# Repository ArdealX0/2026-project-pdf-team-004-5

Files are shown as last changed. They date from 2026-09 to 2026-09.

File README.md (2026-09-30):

Repository Information:

**[Final Report Related Info]**

Lab 004 Team 5-Design Documentation.pdf is the design documentation file. 
  - This file was maintained on Google Doc and the final version is exported here.
  
Lab 004 Team 5-Design Final Report.pdf is the final report.

**[Final Design CAD]**

Model_Parts/Showcase Vehicle v2 CAD.zip contains all the step files of the final project design vehicle exported form OnShape

**[Final Design Code]**

esp32_left_n20_motor_controls.ino is the showcase code for 1 of the ESP32s.
  - Responsible for vehicle drive and pick-up wheel drive.
  
esp32_right_colour_sensing_code.ino is the showcase code for the other ESP32.
  - Responsible for servo actuation and colour sensing.

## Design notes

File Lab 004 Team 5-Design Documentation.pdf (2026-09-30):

# MSE 2202B DESIGN DOCUMENT LAB 4 TEAM 5

## SPECIFICATION AND PLANNING PHASE

Tasks Completed February 13, 2026

- Problem Statement Established
- Goals & Constraints Established
- Vehicle Subsystem Trade Studies Completed

Problem Statement:

Resource extraction operations in hazardous environments need a way to autonomously navigate unknown terrain to identify and retrieve high-value objects (erasers), especially where long distance communication is unreliable. Thus, the objective of this project is to design and build an autonomous mobile robot capable of collecting pencil erasers from a defined area, separating them by colour, and returning them to a base location within a fixed time limit.

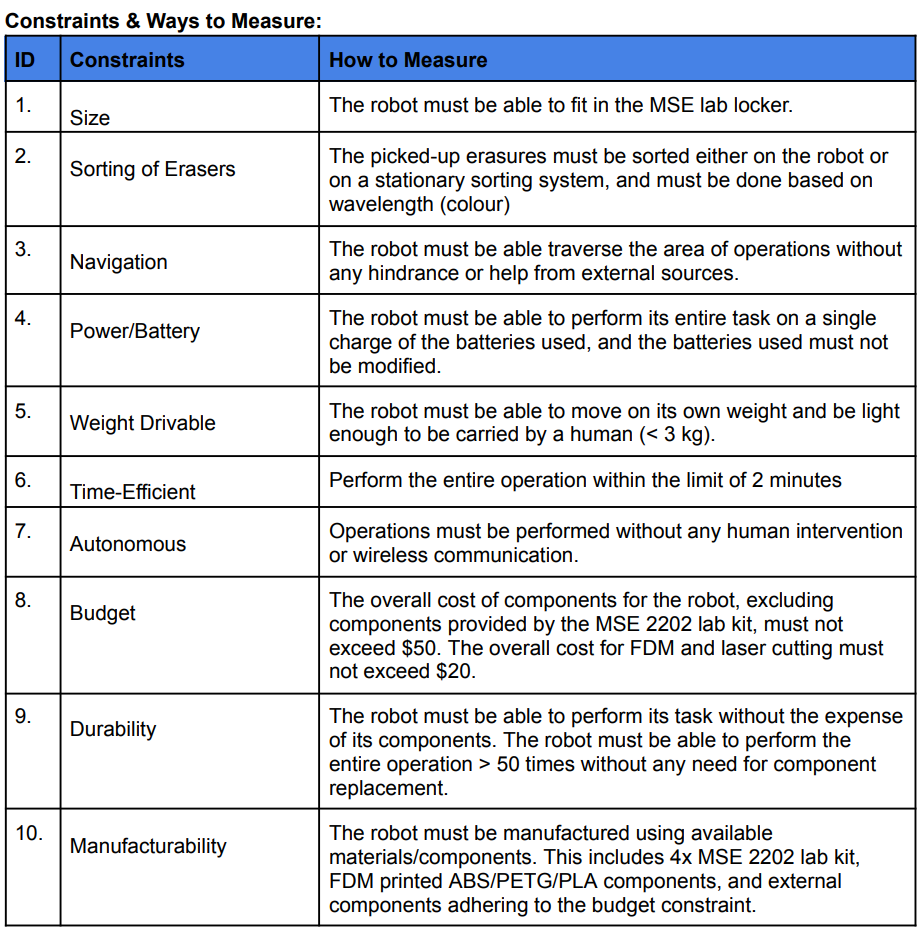
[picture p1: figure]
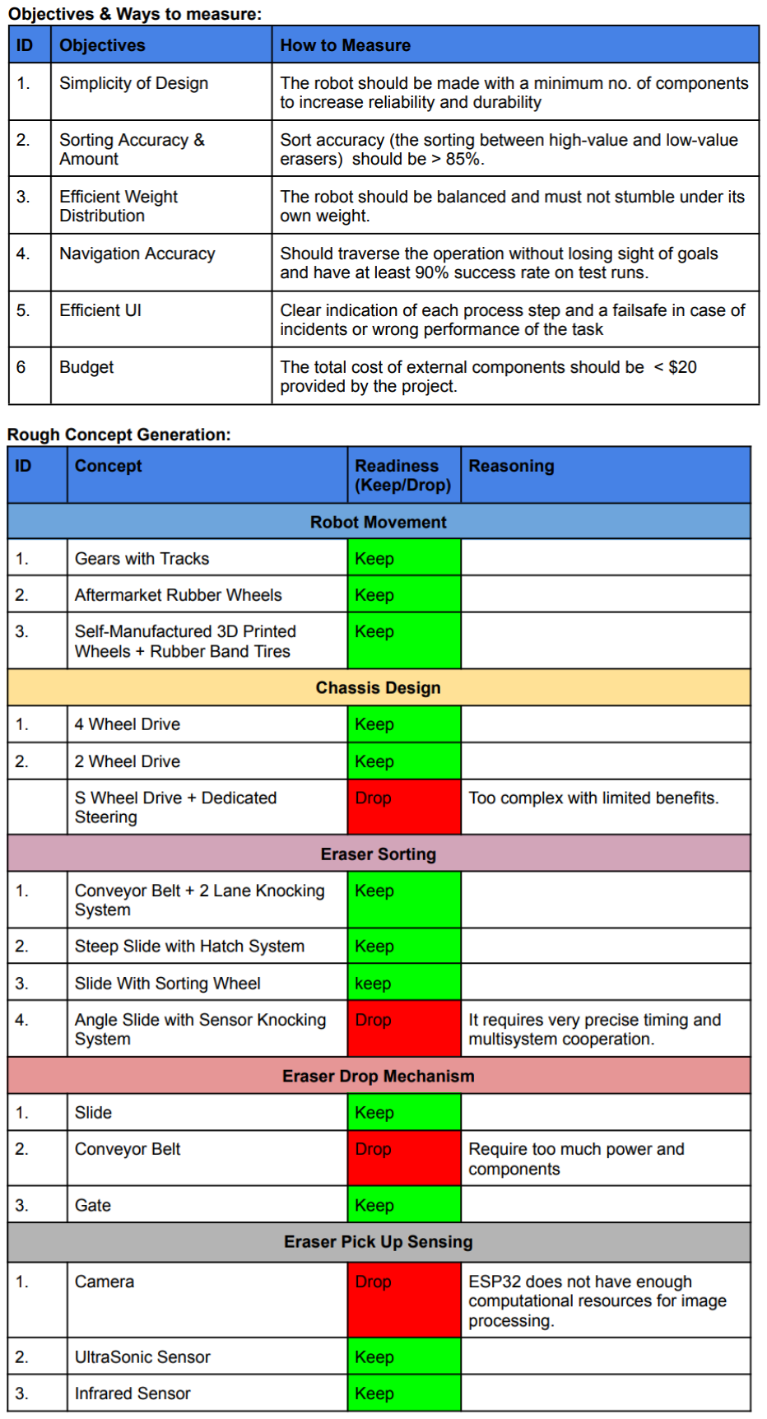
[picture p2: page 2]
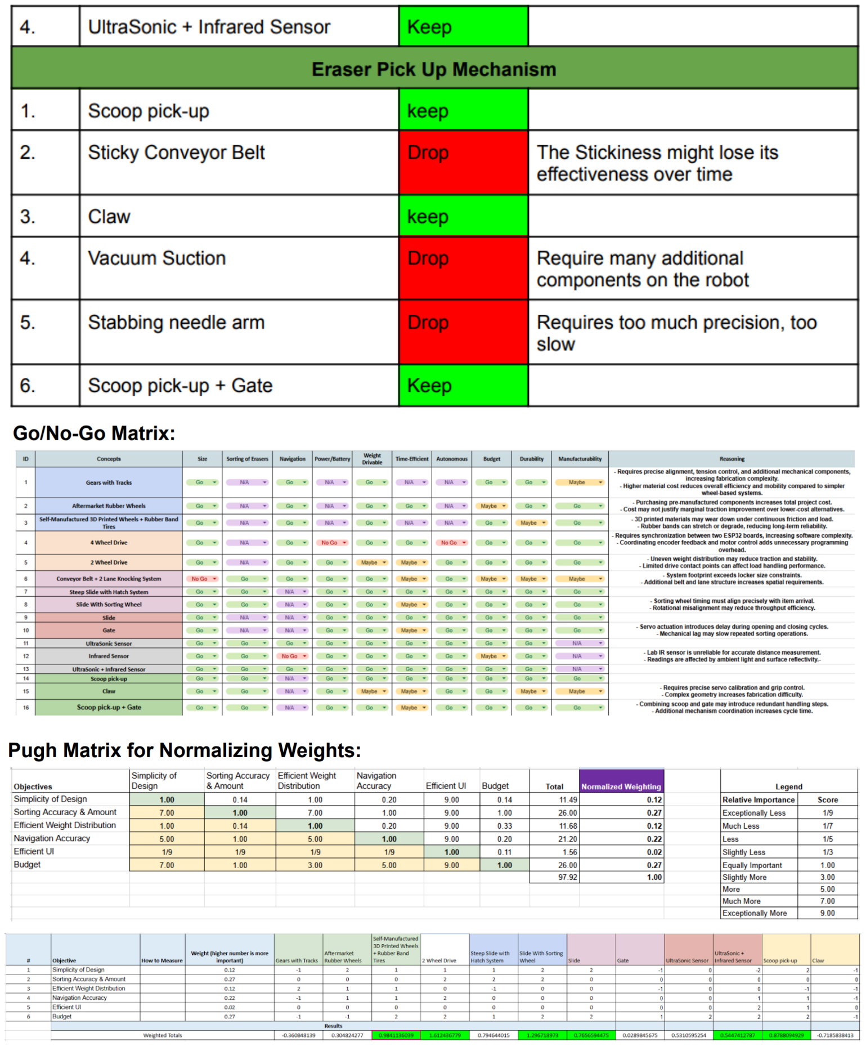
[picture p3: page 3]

## CONCEPTUAL DESIGN PHASE

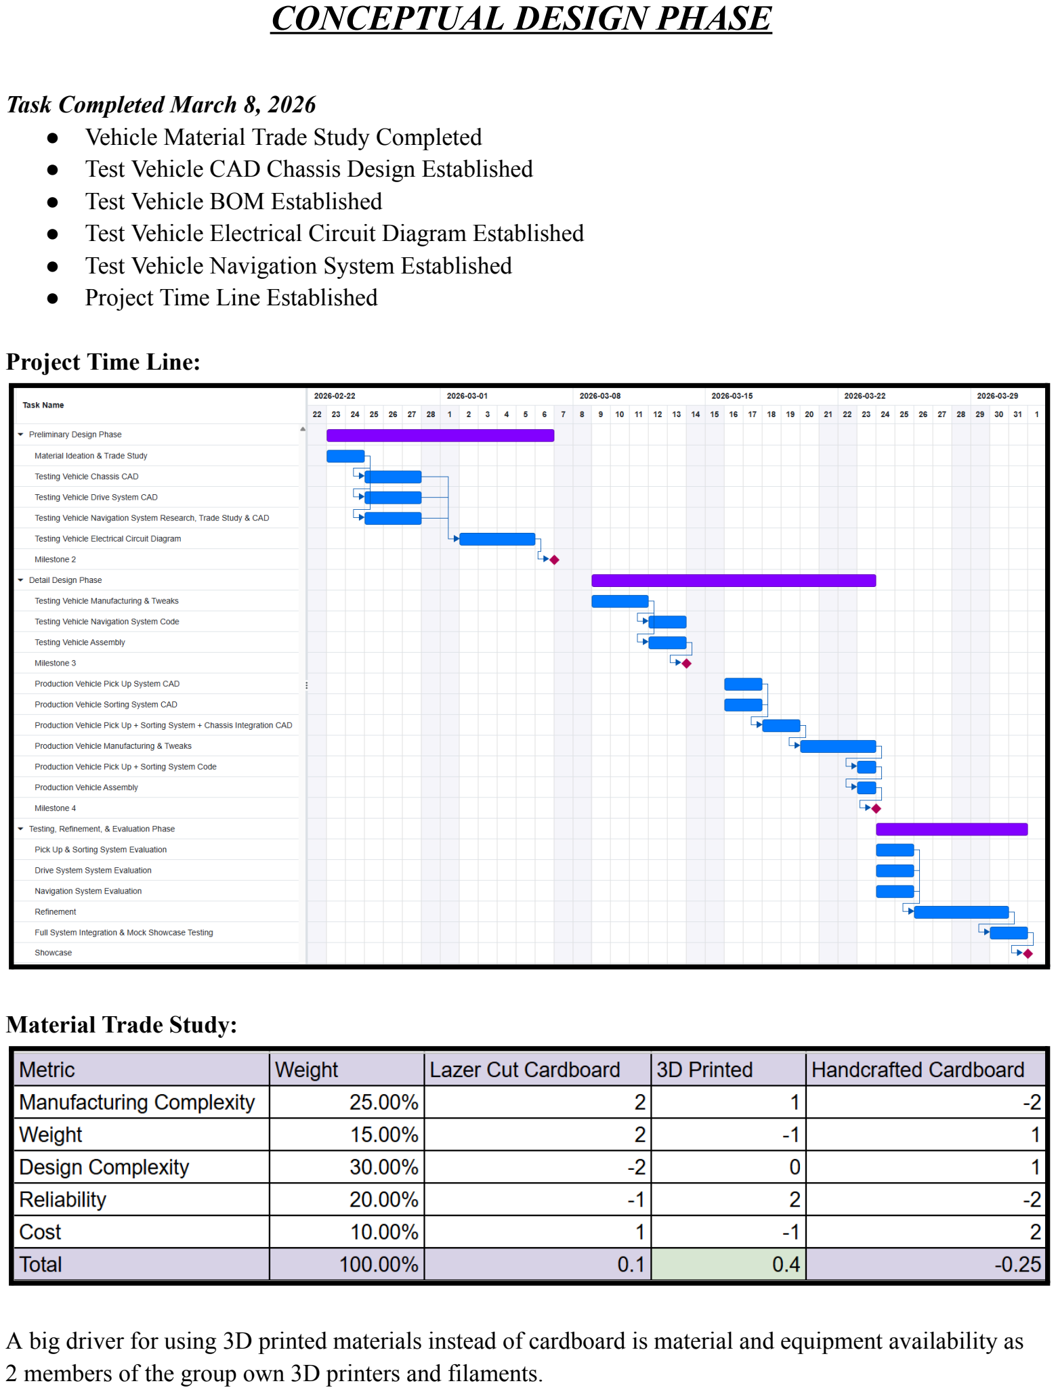
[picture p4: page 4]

Task Completed March 8, 2026
- Vehicle Material Trade Study Completed
- Test Vehicle CAD Chassis Design Established
- Test Vehicle BOM Established
- Test Vehicle Electrical Circuit Diagram Established
- Test Vehicle Navigation System Established
- Project Time Line Established

Project Time Line:

Material Trade Study:

A big driver for using 3D printed materials instead of cardboard is material and equipment availability as 2 members of the group own 3D printers and filaments.

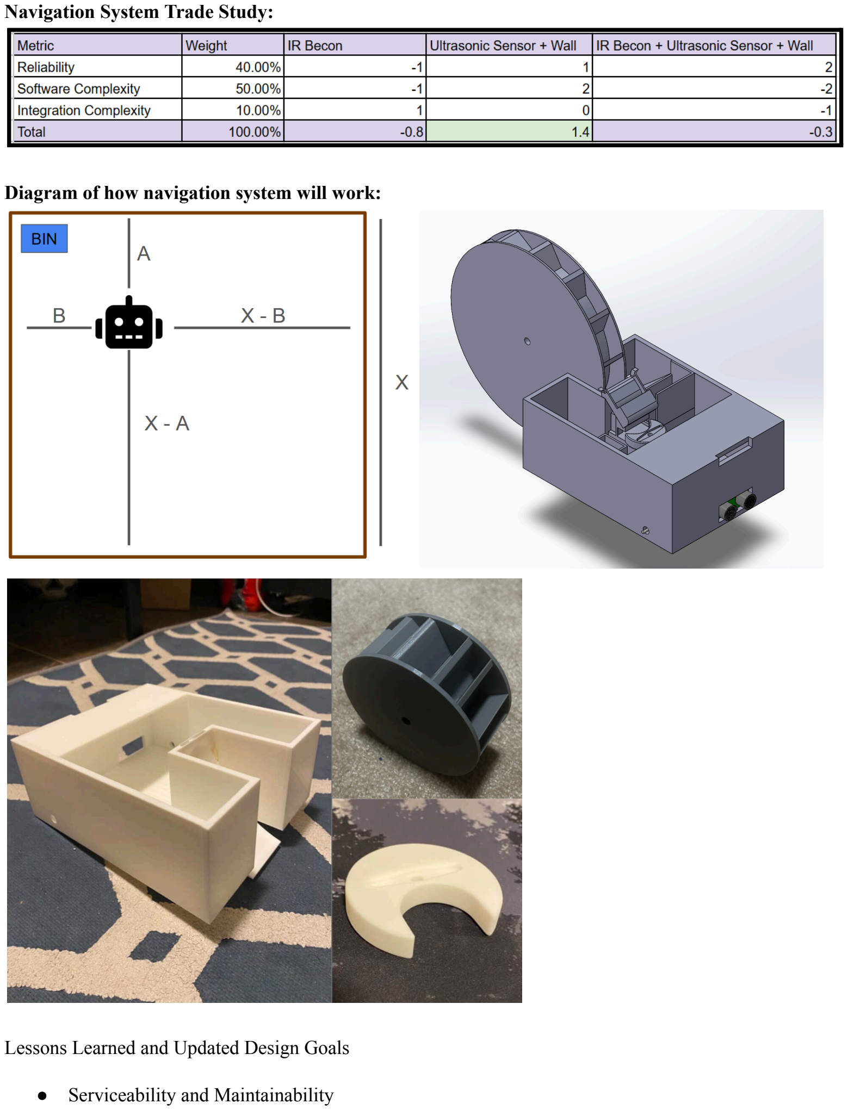
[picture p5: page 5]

Navigation System Trade Study:

Diagram of how navigation system will work:

Lessons Learned and Updated Design Goals

- Serviceability and Maintainability

- The design shall prioritize ease of maintenance by ensuring that frequently failing or high-wear components can be accessed, removed, and replaced without full system disassembly.
- Critical electronic components shall remain accessible in the fully assembled configuration, minimizing downtime during troubleshooting or repair.
- Modular design principles should be implemented, allowing individual subsystems to be serviced independently.
- Ease of Assembly and Disassembly
- The product shall be designed for straightforward assembly using standard tools and minimal steps.
- Components, particularly 3D printed parts, shall be designed as modular subassemblies that can be repeatedly assembled and disassembled without degradation.
- Fastening methods should promote repeatability and alignment, reducing assembly errors and build time.
- Minimization of 3D Printing Supports
- All 3D printed components shall be designed to minimize or eliminate the need for support structures, reducing material usage, print time, and post-processing effort.
- Geometries should incorporate self-supporting angles (≥30° where possible) and avoid overhangs that require excessive support.
- Print Orientation and Structural Integrity
- Parts shall be designed to allow optimal print orientation, ensuring that layer adhesion does not compromise structural performance.
- Load-bearing components must be oriented such that principal stresses are aligned with the strongest print direction (layer plane).
- Design geometry should account for anisotropic material properties inherent to FDM printing.
- Standardization of Fasteners
- The design shall utilize M3 screw wherever possible to simplify manufacturing, assembly, and maintenance.
- Use of non-standard fasteners shall be avoided unless functionally justified (e.g., load requirements, space constraints).
- Dimensional Tolerancing
- General dimensional tolerances shall be maintained at ±0.5 mm to ensure compatibility between interfacing components while accommodating typical manufacturing variability.
- Fits between mating parts (e.g., press-fit, clearance fit) shall be designed with consideration of printer accuracy and material behavior.

Lessons Learned and Updated Constraints

- Manufacturing Capability Constraint (3D Printing)
- The design shall not require dimensional tolerances tighter than ±0.1 mm, reflecting the practical limitations of the Bambu Lab P1S 3D printer.
- Features requiring higher precision shall be redesigned, simplified, or post-processed rather than relying on print accuracy alone.

- All critical dimensions must be validated against realistic printer performance, including variability due to material, calibration, and environmental conditions.

## DETAIL DESIGN PHASE

Task Completed March 13, 2026
- Updated Project Objectives
- Updated Project Constraints
- Test Vehicle Completed
ID | Objectives | How to Measure
O-1 | Simplicity of Design | The robot should be made with a minimum no. of components to increase reliability and durability.
O-2 | Sorting Accuracy & Amount | Sort accuracy (the sorting between high-value and low-value erasers) should be > 85%.
O-3 | Efficient Weight Distribution | The robot should be balanced and must not stumble under its own weight and be as light as possible.
O-4 | Navigation Accuracy | Should traverse the operation without losing sight of goals and have at least 90% success rate on test runs.
O-5 | Efficient UI | Clear indication of each process step and a failsafe in case of incidents or wrong performance of the task
O-6 | Budget | The total cost of external components should be < $20 provided by the project.
O-7 | Design for Serviceability | The design shall prioritize ease of maintenance by ensuring that frequently failing or high-wear components can be accessed, removed, and replaced without full system disassembly. Critical electronic components shall remain accessible in the fully assembled configuration, minimizing downtime during troubleshooting or repair. Modular design principles should be implemented, allowing individual subsystems to be serviced independently.
O-8 | Design for Assembly | The product shall be designed for straightforward assembly using standard tools and minimal steps. Components, particularly 3D printed parts, shall be designed as modular subassemblies that can be repeatedly assembled and disassembled without degradation. Fastening methods should promote repeatability and alignment, reducing assembly errors and build time.

O-9 | Standardization | The design shall utilize M3 screw with M3 5 x 4 mm heated inserts wherever possible to simplify manufacturing, assembly, and maintenance. Use of non-standard fasteners shall be avoided unless functionally justified (e.g., load requirements, space constraints). General dimensional tolerances shall be maintained at ±0.5 mm to ensure compatibility between interfacing components while accommodating typical manufacturing variability.
O-10 | Speed | The amount of time per mission should be minimized < 1 minute.
ID | Constraint | Description
C-1 | Size | The robot must be able to fit in the MSE lab locker.
C-2 | Sorting of Erasers | The picked-up erasures must be sorted either on the robot or on a stationary sorting system, and must be done based on wavelength (colour).
C-3 | Navigation | The robot must be able traverse the area of operations without any hindrance or help from external sources.
C-4 | Power/Battery | The robot must be able to perform its entire task on a single charge of the batteries used, and the batteries used must not be modified.
C-5 | Weight Drivable | The robot must be able to move on its own weight and be light enough to be carried by a human (< 3 kg).
C-6 | Time-Efficient | Perform the entire operation within the limit of 2 minutes.
C-7 | Autonomous | Operations must be performed without any human intervention or wireless communication.
C-8 | Budget | The overall cost of components for the robot, excluding components provided by the MSE 2202 lab kit, must not exceed $50. The overall cost for FDM and laser cutting must not exceed $20.
C-9 | Durability | The robot must be able to perform its task without the expense of its components. The robot must be able to perform the entire operation > 50 times without any need for component replacement.
C-10 | Manufacturability | The robot must be manufactured using available materials/components. This includes 4x MSE 2202 lab kit, FDM printed ABS/PETG/PLA components, and external components adhering to the budget constraint.

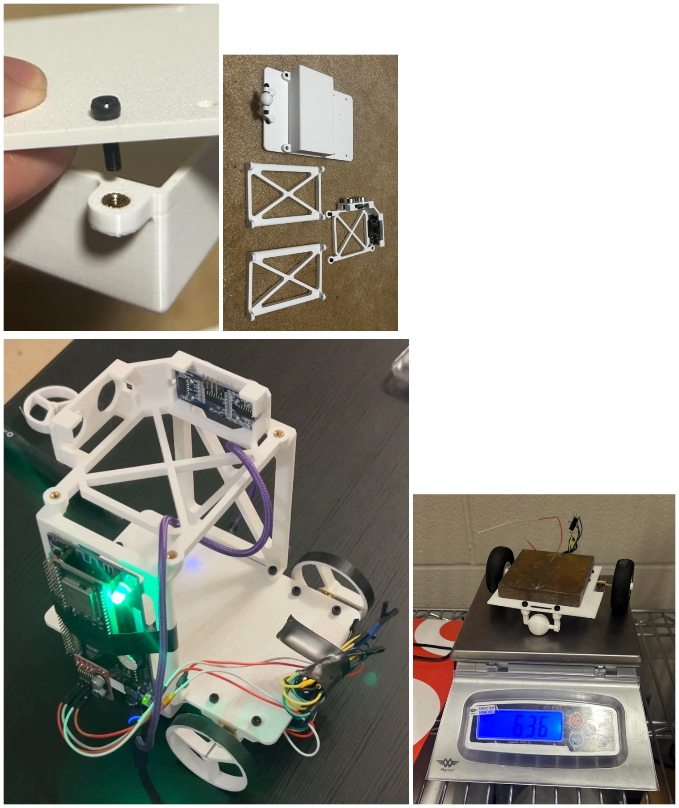
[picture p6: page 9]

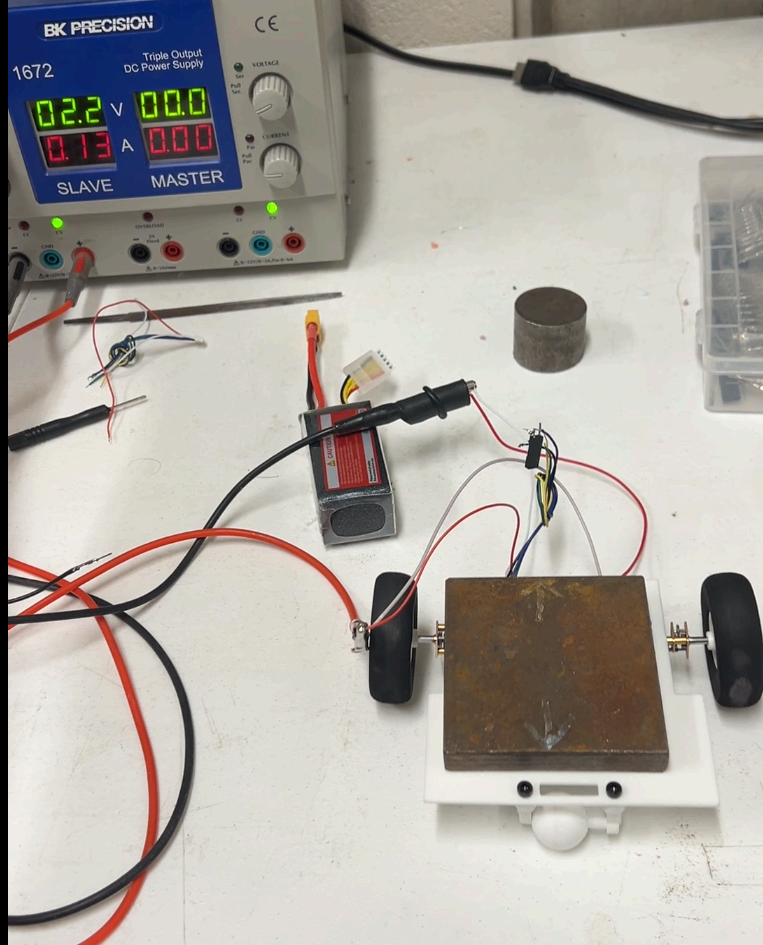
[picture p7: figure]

Task Completed March 24, 2026
- Tested Multiple Pickup System Implementation

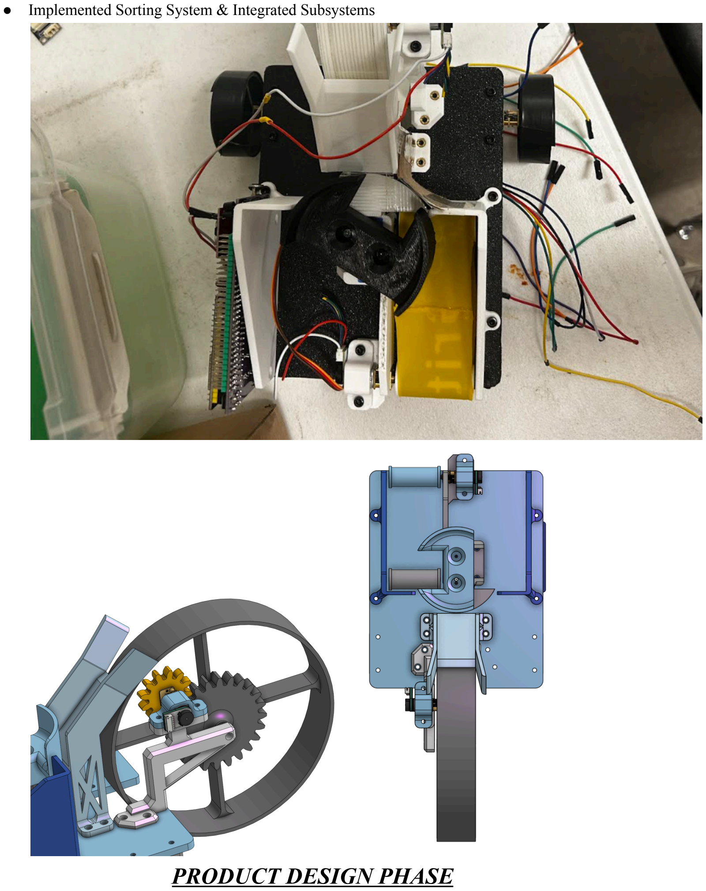
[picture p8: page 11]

- Implemented Sorting System & Integrated Subsystems

## PRODUCT DESIGN PHASE

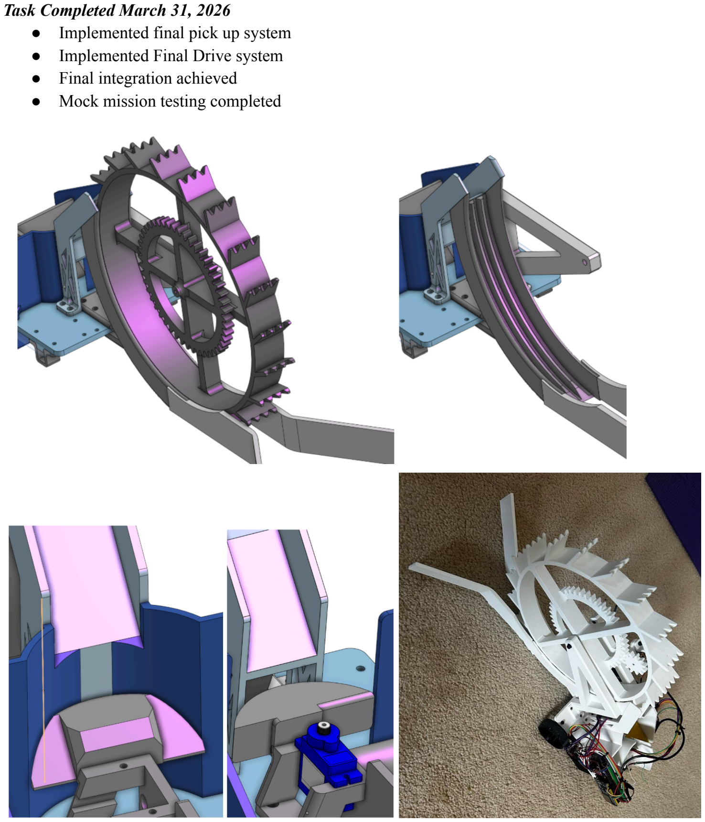
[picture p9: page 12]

Task Completed March 31, 2026
- Implemented final pick up system
- Implemented Final Drive system
- Final integration achieved
- Mock mission testing completed

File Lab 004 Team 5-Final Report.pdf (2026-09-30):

## MSE 2202B FINAL PROJECT DESIGN REPORT

### Lab 4 Team 5

Team Members

Jason Pan
Liam Mcfadden
Anurag Aggarwal
Alan Sanjit

Submission Date: April 9th, 2026

### Executive Summary

This project involved the design, manufacturing, and testing of an autonomous robotic vehicle

capable of collecting, sorting, and returning erasers within a constrained environment. The

system was required to operate within a 120 second time limit while meeting constraints related

to autonomy, cost, and manufacturability.

An iterative design approach was used, where multiple testing vehicles were developed to

identify and resolve design issues. Early challenges in manufacturability, assembly, and

subsystem integration were addressed through modular design, standardization of M3 fasteners,

and improved 3D printing practices.

The final design, Showcase Vehicle v2, consisted of 17 custom 3D printed components with

dimensions of 482 × 192 × 255 mm and a mass of approximately 900 g. The pick up and sorting

systems performed reliably, with the sorting system achieving 100 percent accuracy during the

showcase, satisfying the primary objective of prioritizing sorting accuracy.

The system also met cost and assembly objectives. The total external cost was approximately $9,

and the use of heat set inserts and standardized fasteners improved serviceability and integration.

The main limitation was the navigation system. A time based control approach was used due to

late design constraints, which introduced positional error and prevented full autonomy. As a

result, the vehicle required human assistance and did not meet autonomy requirements.

Overall, the project demonstrated effective iterative design. While full autonomy was not

achieved, the final system met most objectives and provided a reliable solution for eraser

collection and sorting.

Table of Contents

### 1 Introduction

1.1.0 Mission Overview
1.2.0 Scoring Analysis
1.3.0 Goals & Constraints

### 2 Discussion 2.1 Preliminary Design & Trade Studies

2.1.1 Design Decision Structure 2.1.2 Trade Studies
2.1.3 Timeline

### 2.2 Implementation & Iterations

2.2.1 Testing Vehicle Manufacturing 2.2.2 Testing Vehicle Testing
2.2.3 Testing Vehicle Iteration
2.2.4 Showcase Vehicle Manufacturing
2.2.5 Showcase Vehicle Testing
2.2.6 Showcase Vehicle Iteration
2.2.7 Sorting System Software Implementation
2.2.8 Pick Up & Drive System Software Implementation 2.2.9 Electrical Systems

### 3 Conclusion 4 Recommendations

4.1.0 Mechanical
4.2.0 Electrical & Software 4.3.0 Sustainability

List of Figures

Figure 1: Scoring Equation
Figure 2: Design Decision Structure Flow Chart Figure 3: Ultrasonic Sensor + Wall Navigation System Figure 4: Gantt Chart for Project Timeline
Figure 5: Testing Vehicle v1 CAD & 3D Printed Parts Figure 6: Testing Vehicle v2 Weight & Voltage Testing Figure 7: Heated Inserts & Showcase of Design Modularity Figure 8: Test Vehicle v2
Figure 9: Depiction of Testing Vehicle v1 Lift System Flaw
Figure 10: Gear Mechanism of Showcase Vehicle v2
Figure 11: Sorting System & Drop System Design vs. Showcase Vehicle v1 Figure 12: Demonstration of Eraser Getting Stuck 1
Figure 13: Demonstration of Eraser Getting Stuck 2
Figure 14: Demonstration of Eraser Getting Stuck 3
Figure 15: Example of Escalator Groves
Figure 16: Implementation of Escalator Groves on Showcase Vehicle v2 Figure 17: Implementation of Landing Platform Slope
Figure 18: Technical Drawing of Final Design
Figure 19: Implementation of Final Design

List of Tables:

Table 1: Constraints
Table 2: Objectives
Table 3: Concept Generation & Readiness Evaluation Table 4: Go/No-Go Matrix
Table 5: Pugh Matrix Weight Normalization
Table 6: Pugh Matrix
Table 7: Material Trade Study
Table 8: Navigation System Trade Study

### 1.1.0 Mission Overview

In fields such as nuclear cleanup, fire fighting, and active mining operations, there are many environments

that are too dangerous for humans to operate in. To address this, robotic systems are being developed to

enter these areas and retrieve objects of commercial value in their place. This project involves designing

and building one of these systems from the ground up.

The vehicle must start at a base location, navigate a flat open area of up to 15 m², find and collect

valuable erasers identified by their colour, and return them to a 13 x 10 x 8 cm collection container at the

base. The whole task must be completed within 120 seconds. Once started, the robot operates entirely on

its own with no human input.

### 1.2.0 Scoring Analysis

The mission is scored based on an equation involving time (t), number of valuable erasers (g), the number

of waste erasers (b), and the weight of the vehicle (w).

Figure 1: Scoring Equation

The scoring criteria were reviewed early in the design process, and several key implications were

identified:

- The score is negatively impacted by vehicle weight. As a result, Objective O-3 was defined to

minimize overall robot weight.

- The score is also negatively affected by mission completion time. This led to the inclusion of

Objective O-10 to minimize total mission time.

- A penalty is applied for collecting incorrect eraser types. Given the fixed 2-minute time limit, this

places greater importance on sorting accuracy over total collection quantity.

### 1.3.0 Constraints & Objectives

The following outlines the final goals and constraints of the project. Additional goals were introduced

throughout the design process based on manufacturing limitations and insights gained from iterative

development.

Table 1: Constraints
ID | Constraint | Description
C-1 | Size | The robot must be able to fit in the MSE lab locker.
C-2 | Sorting of Erasers | The picked-up erasures must be sorted either on the robot or on a stationary sorting system, and must be done based on wavelength (colour).
C-3 | Navigation | The robot must be able traverse the area of operations without any hindrance or help from external sources.
C-4 | Power/Battery | The robot must be able to perform its entire task on a single charge of the batteries used, and the batteries used must not be modified.
C-5 | Weight Drivable | The robot must be able to move on its own weight and be light enough to be carried by a human (< 3 kg).
C-6 | Time-Efficient | Perform the entire operation within the limit of 2 minutes.
C-7 | Autonomous | Operations must be performed without any human intervention or wireless communication.
C-8 | Budget | The overall cost of components for the robot, excluding components provided by the MSE 2202 lab kit, must not exceed $50. The overall cost for FDM and laser cutting must not exceed $20.
C-9 | Durability | The robot must be able to perform its task without the expense of its components. The robot must be able to perform the entire operation > 50 times without any need for component replacement.
C-10 | Manufacturability | The robot must be manufactured using available materials/components. This includes 4x MSE 2202 lab kit, FDM printed ABS/PETG/PLA components, and external components adhering to the budget constraint.

Table 2: Objectives
ID | Objectives | How to Measure
O-1 | Simplicity of Design | The robot should be made with a minimum no. of components to increase reliability and durability.
O-2 | Sorting Accuracy & Amount | Sort accuracy (the sorting between high-value and low-value erasers) should be > 85%.
O-3 | Efficient Weight Distribution | The robot should be balanced and must not stumble under its own weight and be as light as possible.
O-4 | Navigation Accuracy | Should traverse the operation without losing sight of goals and have at least 90% success rate on test runs.
O-5 | Efficient UI | Clear indication of each process step and a failsafe in case of incidents or wrong performance of the task
O-6 | Budget | The total cost of external components should be < $20 provided by the project.
O-7 | Design for Serviceability | The design shall prioritize ease of maintenance by ensuring that frequently failing or high-wear components can be accessed, removed, and replaced without full system disassembly. Critical electronic components shall remain accessible in the fully assembled configuration, minimizing downtime during troubleshooting or repair. Modular design principles should be implemented, allowing individual subsystems to be serviced independently.
O-8 | Design for Assembly | The product shall be designed for straightforward assembly using standard tools and minimal steps. Components, particularly 3D printed parts, shall be designed as modular subassemblies that can be repeatedly assembled and disassembled without degradation. Fastening methods should promote repeatability and alignment, reducing assembly errors and build time.
O-9 | Standardization | The design shall utilize M3 screw with M3 5 x 4 mm heated inserts wherever possible to simplify manufacturing, assembly, and maintenance. Use of non-standard fasteners shall be avoided unless functionally justified (e.g., load requirements, space constraints). General dimensional tolerances shall be maintained at ±0.5 mm to ensure compatibility between interfacing components while accommodating typical manufacturing variability.
O-10 | Speed | The amount of time per mission should be minimized < 1 minute.

### 2.1.1 Design Decision Structure

For the conceptual design phase, an elimination based approach was used to determine subsystem

configurations. The overall system was decomposed into 6 major subsystems, each with a defined

function:

- Drive System: Responsible for all vehicle motion, including propulsion and turning.
- Chassis: Provides structural support and integrates all subsystems into a single assembly.
- Drop System: Responsible for delivering collected erasers into the scoring bin.
- Sorting System: Determines and directs sorts erasers into the correct bin.
- Pick-Up Sensing / Navigation System: Responsible for vehicle navigation and detection of

erasers.

- Pick-Up Mechanism: Responsible for the physical collection of erasers.

This decomposition allowed each subsystem to be evaluated and developed independently during concept

generation and selection.

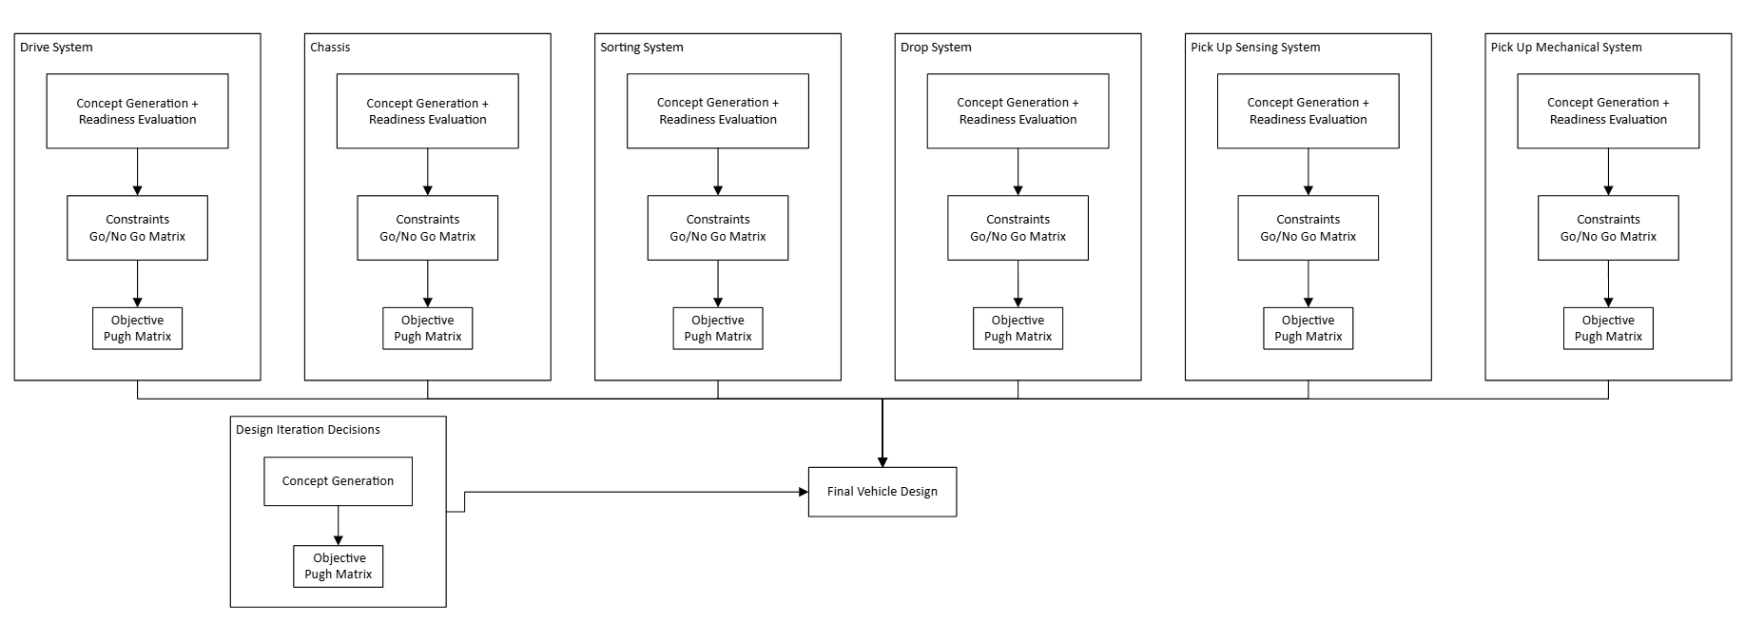
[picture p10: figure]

Figure 2: Design Decision Structure Flow Chart

Each subsystem concept first undergoes a readiness evaluation to identify obvious constraint violations or

design flaws, allowing weak concepts to be eliminated early. Concepts that pass this stage are then

evaluated using a Go/No-Go matrix to ensure compliance with all design constraints.

Following this, remaining concepts are further refined and compared using a Pugh matrix to support final

selection of subsystem configurations. Evaluation criteria are assigned weights based on their relative

importance, which are then normalized such that their total sums to 1.0. This ensures each criterion

contributes proportionally to the final score and prevents any single category from dominating the

decision unless intentionally weighted. This improves consistency and allows for clearer justification

when comparing concepts across different metrics.

For design issues identified after the conceptual phase (e.g., during preliminary design or manufacturing),

an expedited evaluation process is used. In these cases, concepts are assessed using a simplified Pugh

matrix without weight normalization and parameters will be graded from -2 to 2. This reduces evaluation

time and allows for faster implementation within the limited time between milestone deadlines, at the

expense of reduced analytical rigor.

### 2.1.2 Trade Studies

Table 3: Concept Generation & Readiness Evaluation
ID | Concept | (Keep/Drop) | Reasoning
| | Robot Movement
1. | Gears with Tracks | Keep
2. | Aftermarket Rubber Wheels | Keep
3. Self-Manufactured 3D Printed Wheels | + Rubber Band Tires | Keep

Chassis Design

1. | 4 Wheel Drive | Keep
2. | 2 Wheel Drive | Keep
| S Wheel Drive + Dedicated Steering | Drop | Too complex with limited benefits.

Eraser Sorting

1. Conveyor Belt + 2 Lane Knocking
System

Keep

2. | Steep Slide with Hatch System | Keep
3. | Slide With Sorting Wheel | keep
4. Angle Slide with Sensor Knocking | System | Drop | It requires very precise timing and multisystem cooperation.

Eraser Drop Mechanism

1. | Slide | Keep
2. | Conveyor Belt | Drop | Require too much power and components.
3. | Gate | Keep

Eraser Pick Up Sensing

1. | Camera | Drop | ESP32 does not have enough computational resources for image processing.
2. | UltraSonic Sensor | Keep
3. | Infrared Sensor | Keep
4. | UltraSonic + Infrared Sensor | Keep

Eraser Pick Up Mechanism

1. | Scoop pick-up | keep
2. | Sticky Conveyor Belt | Drop | Stickiness might lose its effectiveness over time.
3. | Claw | keep
4. | Vacuum Suction | Drop | Require many additional components on the robot.
5. | Stabbing needle arm | Drop | Requires too much precision, too slow.
6. | Scoop pick-up + Gate | Keep

Table 4: Go/No-Go Matrix

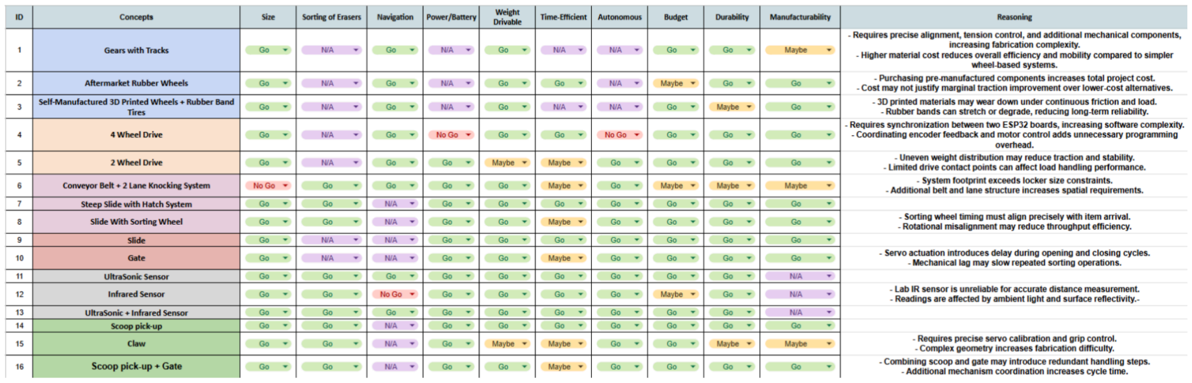
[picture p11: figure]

Table 5: Pugh Matrix Weight Normalization

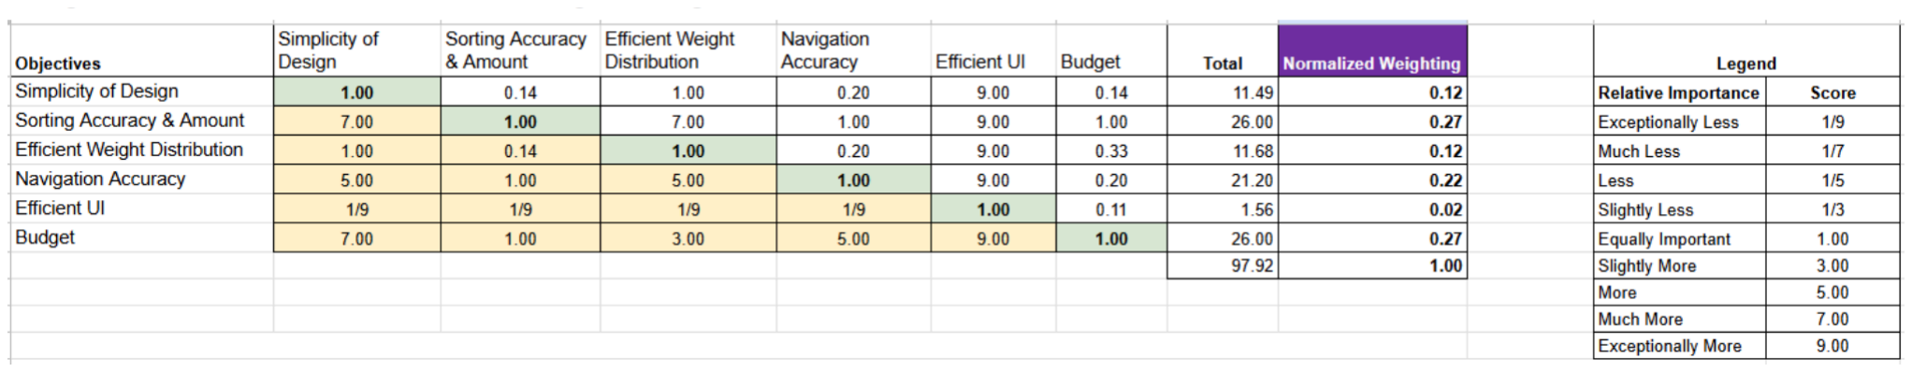
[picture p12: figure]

Table 6: Pugh Matrix

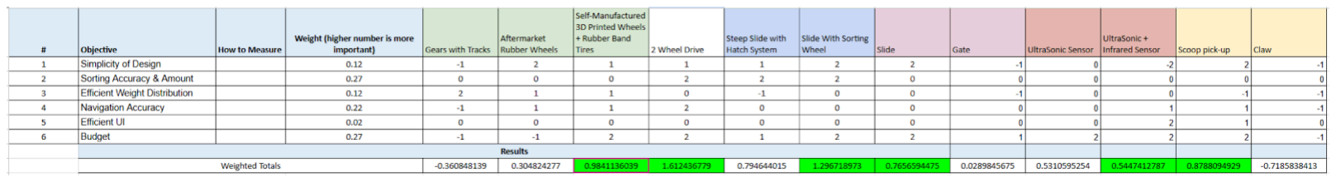
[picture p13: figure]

Table 7: Material Trade Study
Metric | Weight | Laser Cut Cardboard | 3D Printed | Handcrafted Cardboard
Manufacturing Complexity | 25.00% | 2 | 1 | -2
Weight | 15.00% | 2 | -1 | 1
Design Complexity | 30.00% | -2 | 0 | 1
Reliability | 20.00% | -1 | 2 | -2
Cost | 10.00% | 1 | -1 | 2
Total | 100.00% | 0.1 | 0.4 | -0.25

Material selection was performed after the conceptual phase as a design iteration decision using a

simplified trade study. 3D printing was selected as it scored the highest and offered high accessibility,

with 2 team members having direct access to printers, enabling faster iteration and prototyping.

Table 8: Navigation System Trade Study
Metric | Weight | IR Becon | Ultrasonic Sensor + Wall | IR Beacon + Ultrasonic Sensor + Wall
Reliability | 40.00% | -1 | 1 | 2
Software Complexity | 50.00% | -1 | 2 | -2
Integration Complexity | 10.00% | 1 | 0 | -1
Total | 100.00% | -0.8 | 1.4 | -0.3

The navigation system metrics were revised after the

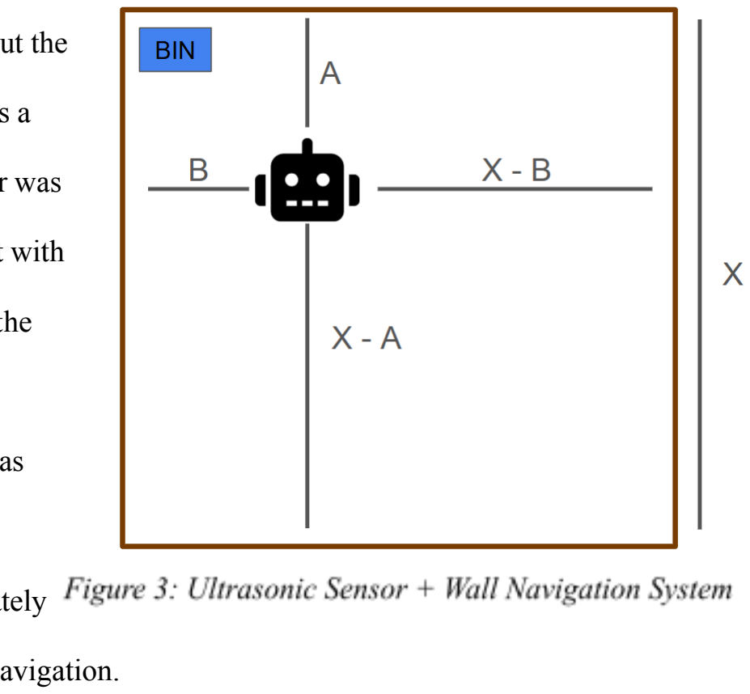
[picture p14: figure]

conceptual phase due to an incorrect assumption about the

capabilities of the infrared sensor. This was treated as a

design iteration decision. Initially, the infrared sensor was

assumed to be able to detect eraser colours and assist with

navigation. Testing showed this was not feasible, as the

sensor could not reliably differentiate colours in this

application. As a result, the navigation trade study was

redone based on realistic sensor performance. The

ultrasonic sensor with a surrounding wall was ultimately

selected, as it provided more reliable detection and navigation.

### 1.4.0 Project Timeline

A project timeline was established following Milestone 1 to guide the development of both the testing and

showcase vehicles. The work was divided into three phases, each consisting of tasks scheduled based on

expected completion time and milestone deadlines. Subsystems were developed in parallel where

possible, while still accounting for dependencies such as integration and manufacturing. The Gantt chart

reflects this through overlapping design, manufacturing, and testing, with time allocated for iteration.

1. “Preliminary Design Phase”: This phase focuses on developing the core subsystems. Work includes

material trade studies and initial CAD for the chassis, drive system, navigation system, and electrical

layout. Most CAD is completed here and refined to a manufacturable level. Subsystems are developed in

parallel while considering integration. By Milestone 2, major design decisions are finalized and the design

is ready for manufacturing.

2. “Detailed Design Phase”: This phase focuses on physical implementation and refinement. The testing

vehicle is manufactured first, followed by development of a showcase vehicle which includes subsystems

such as pick-up, sorting, and chassis integration. Issues such as fitment, alignment, and tolerance stack-up

are expected, and time is allocated for iteration. Manufacturing also establishes standards for tolerances,

fasteners, and assembly. Software is developed alongside hardware integration. This phase ends with a

fully assembled system (Milestone 4).

3. “Testing, Refinement, and Evaluation Phase”: This phase focuses on validating performance and

making final adjustments. Subsystems are tested individually before full system testing. Results are

compared against design expectations, and issues are addressed through targeted refinements. The phase

ends with full system integration and a final showcase under expected operating conditions, ensuring the

system is reliable and consistent.

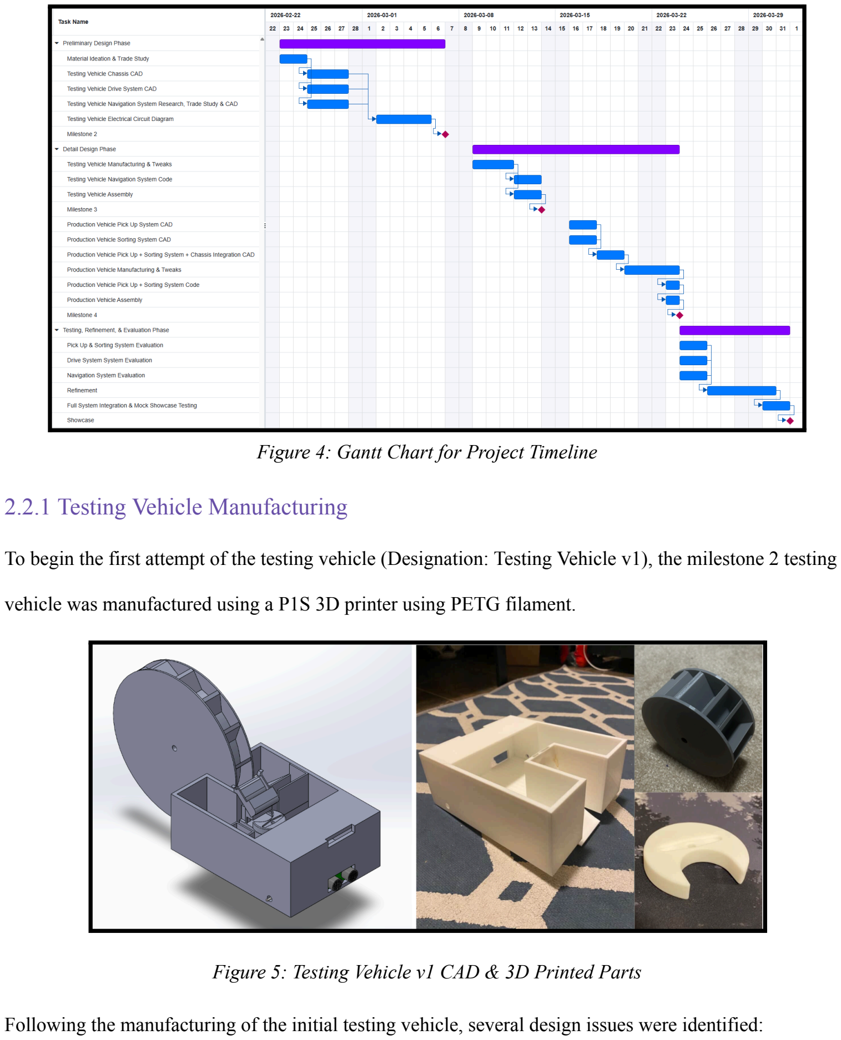
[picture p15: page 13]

Figure 4: Gantt Chart for Project Timeline

### 2.2.1 Testing Vehicle Manufacturing

To begin the first attempt of the testing vehicle (Designation: Testing Vehicle v1), the milestone 2 testing

vehicle was manufactured using a P1S 3D printer using PETG filament.

Figure 5: Testing Vehicle v1 CAD & 3D Printed Parts

Following the manufacturing of the initial testing vehicle, several design issues were identified:

1. The design required extensive 3D printing support. Due to multiple overhangs, there was no

viable print orientation that significantly reduced support usage, leading to increased print time

and post processing.

2. The vehicle was difficult to assemble and service. Many components were designed as single

large parts, making internal features hard to access. This also increased iteration time, as small

errors required reprinting entire parts.

3. Material usage was inefficient. Excess filament was used due to unnecessarily thick walls and

fully solid geometries where weight reduction features (e.g., cutouts) could have been

implemented.

4. Part integration was inconsistent. A lack of standardization in connection methods led to poor fit

between components and required additional adjustments during assembly.

5. Collaboration in CAD was very limited. Subsystems were developed independently by each team

member on local SolidWorks files, making it difficult to track changes across components. This

resulted in integration issues and frequent redesigns.

6. Vehicle weight became a concern, particularly regarding the capability of the N20 motors to drive

the system. Analytical estimation was attempted but was inconclusive, indicating the need for

physical testing.

These shortcomings of the initial design was evaluated and goals O-7, O-8, and O-9 was established

along with the following design principles:

- Minimization of 3D Printing Supports
- All 3D printed components shall be designed to minimize or eliminate the need for

support structures, reducing material usage, print time, and post processing effort.

- Geometries should incorporate self supporting angles (≥30° where possible) and avoid

overhangs that require excessive support.

- Print Orientation and Structural Integrity

- Parts shall be designed to allow optimal print orientation, ensuring that layer adhesion

does not compromise structural performance.

- Load-bearing components must be oriented such that principal stresses are aligned with

the strongest print direction (layer plane).

- Design geometry should account for anisotropic material properties inherent to FDM

printing.

- Dimensional Tolerancing
- General dimensional tolerances shall be maintained at ±0.5 mm to ensure compatibility

between interfacing components while accommodating typical manufacturing variability.

### 2.2.2 Testing Vehicle Testing

To evaluate the capability of the N20 motors, a simplified redesign (Designation: Testing Vehicle v2) was

created using Onshape. The design incorporated several updated goals and constraints, and was then

printed and assembled. The vehicle was configured with an approximation of the final electrical system

by connecting the N20 drive motors directly to a DC power supply, allowing input voltage to be

monitored during testing.

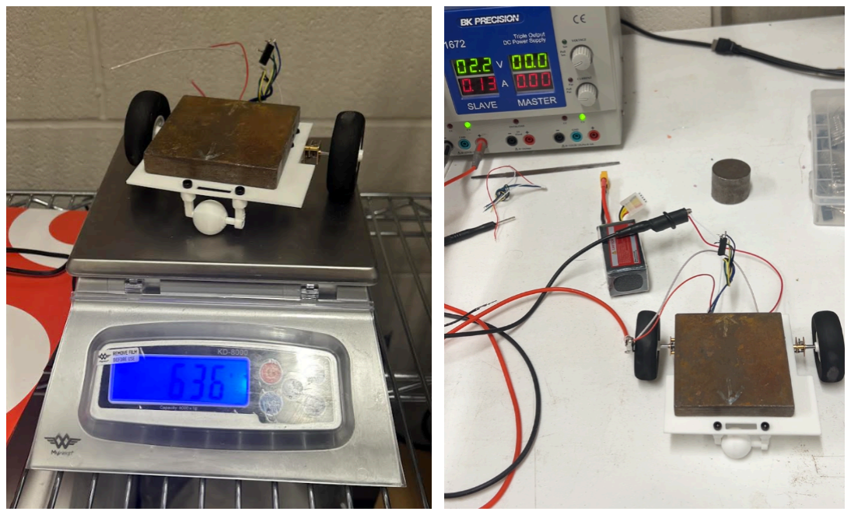
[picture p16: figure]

Figure 6: Testing Vehicle v2 Weight & Voltage Testing

A load of ~630 g, representing the predicted final vehicle weight, was applied. Testing showed that the

vehicle was able to initiate movement at ~2.0 V, which is below the expected operating voltage of 5 V.

Based on this, the N20 motors were determined to be sufficient for the application.

### 2.2.3 Testing Vehicle Iteration

Building on the foundation established by Testing Vehicle v2, Testing Vehicle v3 was developed for

Milestone 3, incorporating the updated goals, constraints, and integration of the navigation system. The

design was made significantly more modular, with components separated wherever possible to improve

manufacturability and reduce print complexity, especially after the introduction of structural cutouts.

Connections between components were standardized using M3 screws paired with heatset threaded

inserts. Heatset inserts were selected due to their ease of installation, as they can be directly embedded

into printed parts, and their ability to provide durable, repeatable threads in plastic. Compared to directly

threading into printed material, inserts significantly reduce wear and risk of stripping, especially under

repeated assembly and disassembly.

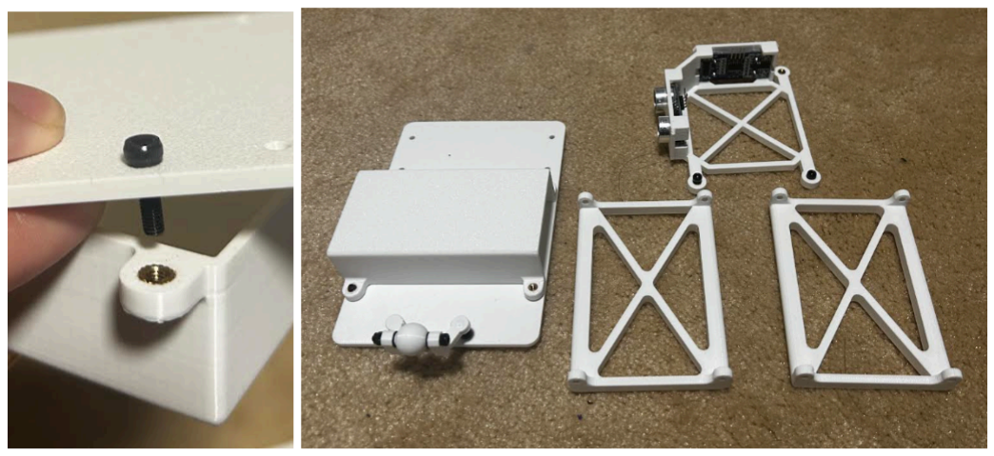
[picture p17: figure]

Figure 7: Heated Inserts & Showcase of Design Modularity

This approach improves serviceability and assembly

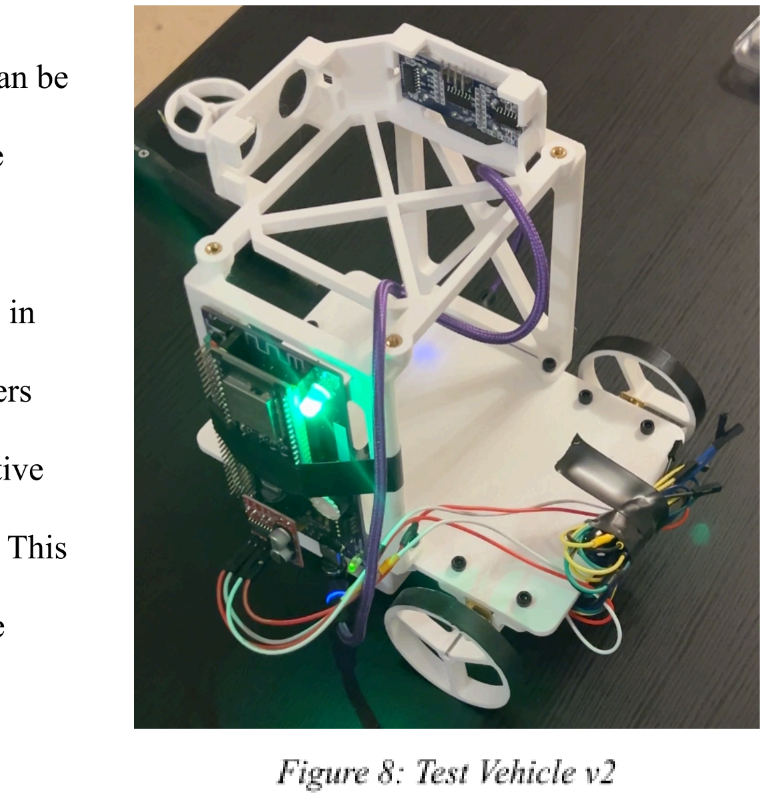
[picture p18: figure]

efficiency (Objectives O-7 and O-8), as components can be

quickly removed and reattached without degrading the

connection. It also eliminates the need for loose nuts,

reducing the risk of part loss and simplifying handling in

constrained spaces. Additionally, standardizing fasteners

across the design improves team collaboration (Objective

O-9), as all members work with a consistent interface. This

reduces integration issues and allows subsystems to be

developed more independently without compatibility

concerns.

### 2.2.4 Showcase Vehicle Manufacturing

Showcase Vehicle v1 initially reused the pick-up system from

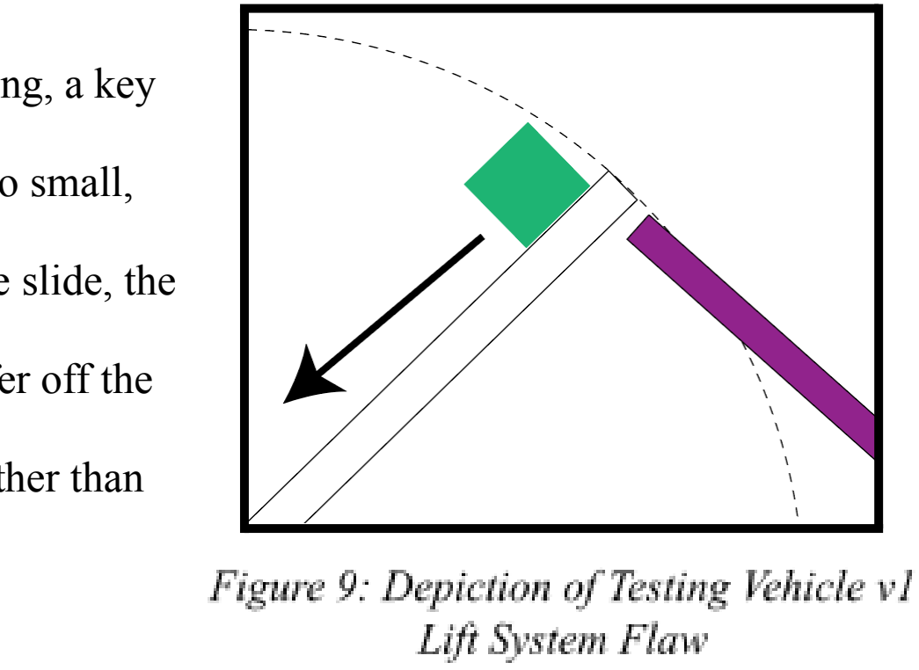
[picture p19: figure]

Testing Vehicle v1. However, during integration and testing, a key

design oversight was identified. The lift geometry was too small,

such that when the mechanism rotated to the height of the slide, the

eraser did not have sufficient clearance or travel to transfer off the

lift. As a result, the eraser remained trapped on the lift rather than

being guided onto the next stage of the system.

Two solutions were considered:

- Replace the lift mechanism with a stick-based system, where erasers would adhere to the surface

of the lift and be carried from the top side of the rotating wheel

- Increase the diameter of the wheel to approximately 25 cm, allowing sufficient space within the

lift geometry for the eraser to naturally slide onto the transfer surface

The stick-based system was ultimately selected. While increasing

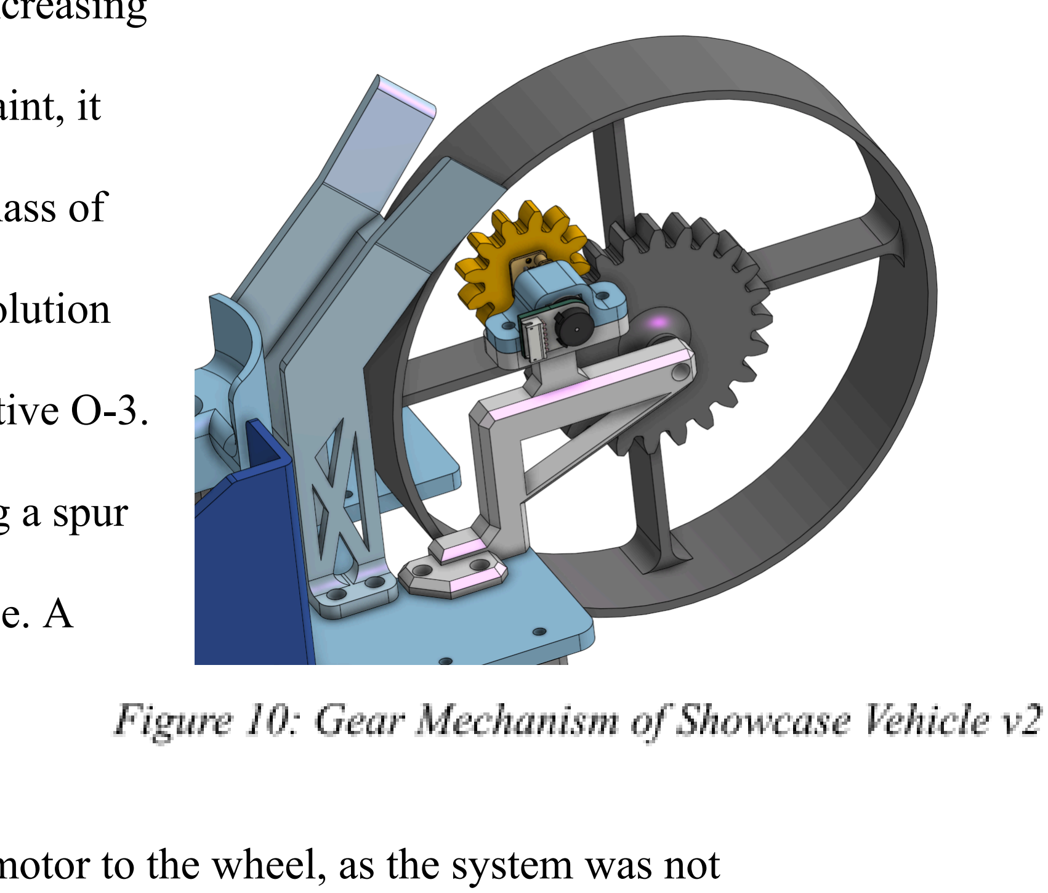
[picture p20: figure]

the wheel size would have resolved the geometric constraint, it

would have significantly increased the overall size and mass of

the system. The stick system provided a more compact solution

and contributed to weight reduction, aligning with Objective O-3.

The rotation of the pick-up wheel was implemented using a spur

gear system designed through a custom plugin in Onshape. A

gear ratio of 1:2 was selected to increase output torque.

This decision was made instead of directly coupling the motor to the wheel, as the system was not

expected to operate under ideal conditions. Resistance from eraser contact, friction, and potential

misalignment during pickup were all anticipated, and the increased torque provided by the gear reduction

improved reliability under these conditions.

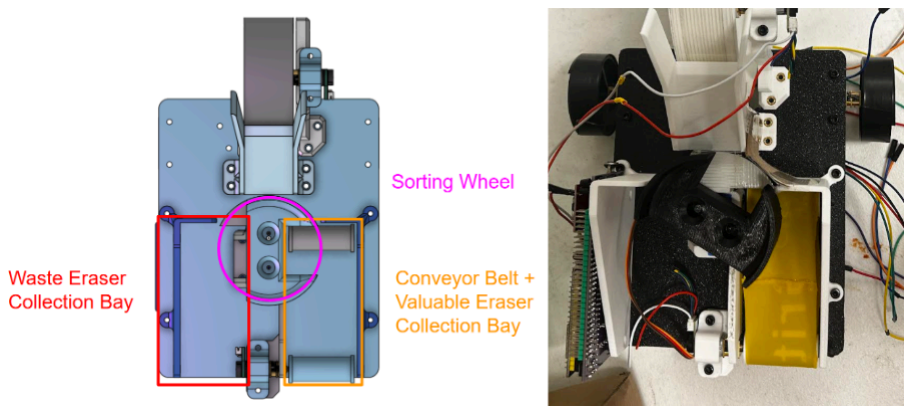
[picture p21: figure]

Figure 11: Sorting System & Drop System Design vs. Showcase Vehicle v1

Following this, the pick-up system was integrated with the sorting system. The sorting system consisted

of a rotating sorting wheel positioned above two collection bays, one on each side. The intent was to

direct erasers into the correct bin based on sorting logic. An eraser drop mechanism using a servo was

initially implemented to push erasers from the platform into the bins. However, testing revealed that the

servo did not produce sufficient torque to reliably move the erasers, especially under conditions where

multiple erasers or increased friction were present. As a result, this approach was deemed unreliable. To

resolve this, a conveyor based transport system was designed and implemented. This system moved

erasers from the pick-up region, beneath the rotating wheel, and into the appropriate collection bins.

### 2.2.5 Showcase Vehicle Testing

During testing of Showcase Vehicle v1, multiple issues were identified:

- Problem 1: The eraser slot is too shallow, causing the eraser to become trapped between the walls

of the sorter wheel and the slide during rotation. This results in the sorter wheel stalling.

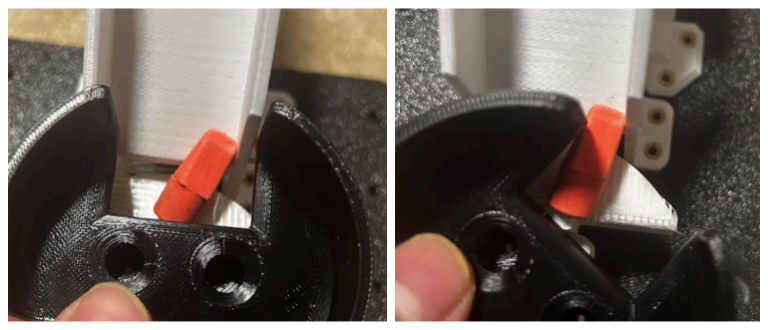
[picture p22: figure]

Figure 12: Demonstration of Eraser Getting Stuck 1

- Problem 2: Erasers can become lodged in the gap beneath the sorter wheel, again preventing

proper rotation and causing the system to stall.

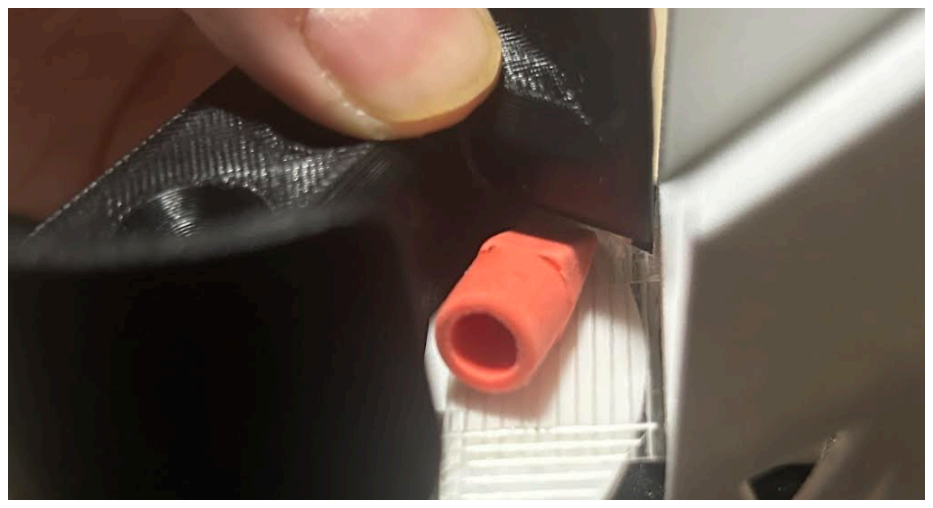
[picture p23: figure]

Figure 13: Demonstration of Eraser Getting Stuck 2

- Problem 3: At the sorted position, the ramp geometry is too large, which in some cases prevents

the eraser from falling into the collection area, reducing reliability of the drop system.

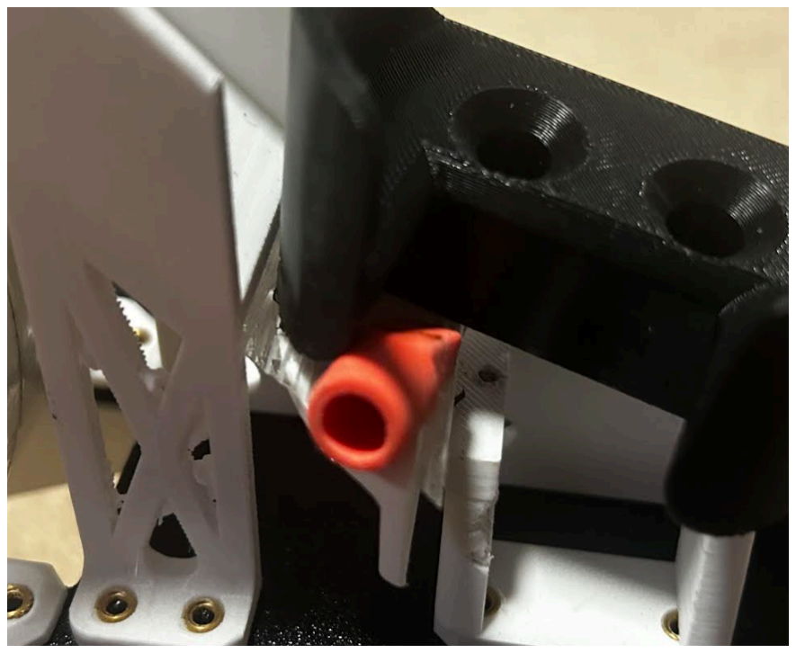
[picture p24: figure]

Figure 14: Demonstration of Eraser Getting Stuck 3

- Problem 4: The stick based lift system did not perform as expected. The surface coating of the

erasers prevented reliable adhesion to the wheel. Multiple adhesives were tested, including tensile

tape, alien tape, and duct tape; however, changes in adhesive type had minimal impact on

performance. It was determined that the eraser surface properties were the limiting factor, making

this approach inherently unreliable.

### 2.2.6 Showcase Vehicle Iteration

Based on the testing results, the design reverted to the second option of using the original lift concept with

an increased wheel diameter marking the beginning of Show Case Vehicle v2. This change ensured

sufficient clearance for the eraser to transfer properly onto the slide. Testing of the sorting system also

revealed that the erasers, due to their “gummy” material properties, were highly prone to getting stuck in small gaps, even at tolerances as low as 0.5 mm. To address this, grooves were introduced into the slide of

the pick-up system.


Figure 15: Example of Escalator Groves


Figure 16: Implementation of Escalator Groves on Showcase Vehicle v2

This approach was inspired by escalator designs, where grooves are used to prevent soft materials, such as

shoe soles, from getting caught in gaps. Additionally, the increased wheel diameter resulted in higher

torque requirements when overcoming resistance from the erasers. To compensate for this, the gear ratio

was increased to 1:4, providing additional torque and improving the reliability of the pick-up mechanism

under load.

One issue introduced by the addition of grooves was related to manufacturability. The teeth geometry on

the wheel would typically require significant 3D printing support, increasing material usage and

post-processing time. Removing support from small features such as teeth is also time consuming and can negatively affect surface quality. It was also observed from previous iterations that surfaces printed

without support consistently resulted in better dimensional accuracy and smoother finishes, while

supported regions showed reduced tolerance and rougher surfaces. To address this, the groove and tooth

geometry were redesigned to be self supporting in the selected print orientation. The features were angled

at approximately 29° relative to the horizontal, keeping them below the typical ~30° threshold where

support is required. This allowed the benefits of the groove design to be retained without introducing

additional support material or compromising print quality.

For the sorting system, a slope was implemented on the landing platform so that the erasers will fall more

easily to the collection bay when pushed by the sorter wheel, mitigating problem 3. The height of the slide

was also raised so that it matched the height of the eraser; mitigating problem 1. Last, the landing

platform was raised to decrease the space between it and the sorting wheel; mitigating problem 2.


Figure 17: Implementation of Landing Platform Slope

### 2.2.7 Sorting System Software Implementation

The implementation aimed to determine threshold values for the TCS34725 colour sensor to reliably

classify colours (red, green, blue, yellow, orange, purple, pink, black, and white) for a sorting mechanism,

while maintaining robustness against lighting variation and sensor noise.

Raw sensor data consists of Red (R), Green (G), Blue (B), and Clear (C) channels, where C represents

brightness. To improve stability, 10 samples are averaged using r = rSum / cNumSamples, g = gSum /

cNumSamples, b = bSum / cNumSamples, and c = cSum / cNumSamples. This reduces noise, smooths

lighting fluctuations, and improves repeatability.

To remove brightness dependence, RGB values are normalized by computing:

sum = r + g + b

r = r / sum

g = g / sum

b = b / sum

This ensures colour detection is based on relative proportions rather than absolute intensity.

Experimental data was collected using normalized values and brightness (C), revealing clear patterns

between colours. For example, orange showed r ≈ 0.58, g ≈ 0.22, b ≈ 0.20; pink showed r ≈ 0.54,

g ≈ 0.20, b ≈ 0.25; green had g ≈ 0.50; white had balanced RGB with high brightness (~600); and

black had very low brightness with balanced RGB.

Thresholds were derived from these patterns. Brightness based classification was applied first: black was

defined as C < 40, and white as C > 300 with balanced RGB. Primary colours were detected using

dominant channels, with green identified by g > 0.45 and blue by b > 0.45 with C > 60 to avoid low

light errors.

Mixed colours were classified using combined thresholds: orange (r > 0.52, g > 0.18, b < 0.25), pink

(r > 0.50, b > 0.22, g < 0.30), yellow (r > 0.32, g > 0.35, b < 0.28), and purple (b > 0.35, r

> 0.28, g < 0.32).

To prevent overlap, a priority order was used: black/white to strong colours (green, blue) to mixed colours

(yellow, orange, purple, pink) to red (default). This ensures more specific conditions are evaluated first.

After calibration, the system achieved accurate detection of all colours. Misclassifications (e.g., orange as

red, yellow as unknown) were eliminated, and the system became robust to lighting changes (via

normalization) and noise (via averaging).

Limitations include reduced accuracy at very low brightness, the need for closer proximity for blue due to

low reflectivity, and sensitivity between similar colours (e.g., pink vs red) under varying lighting.

Overall, the implementation combines empirical calibration, normalization, and iterative threshold

refinement to achieve reliable classification and integration with the sorting system. Improvements could

include using HSV colour space, automatic calibration, dynamic threshold storage, and confidence

scoring.

### 2.2.8 Pick Up & Drive Software Implementation

For the navigation system proposed in the preliminary design phase, it was determined late in the detailed

design phase that the approach was not viable. The design required the field to be surrounded by walls,

which was later confirmed to violate mission rules after consultation with the TA. As a result, the

navigation strategy was dropped. Due to limited time remaining in the project, a simplified hardcoded

approach was implemented. This method used a timing loop within the code to track elapsed time and

controlled motion. Based on predefined time intervals obtained through trial and error, the robot was

commanded to move by sending PWM signals directly to the motors.

However, this approach introduced positional error, as movement was based solely on time rather than

sensor feedback. Variations in motor speed, surface friction, and interaction with erasers led to

accumulated error in position tracking. As a result, complex movement paths were not reliable, and the

robot could not consistently return to its starting position, violating constraint C-7.

To mitigate this, the motion strategy was simplified to a linear forward and back path. This reduced

accumulated error and improved repeatability, as it minimized variability in travel distance and system

response.

A similar approach was applied to the pick-up wheel. During testing, it was observed that erasers could

become lodged between the floor and the lifting mechanism depending on their orientation, causing the

wheel to stall. To address this, a “jitter” motion was implemented in the control logic. The wheel was

programmed to rotate in the lifting direction for a fixed duration, followed by a brief reverse rotation (0.5

s). This reverse motion was sufficient to dislodge stuck erasers, allowing them to be repositioned and

picked up in the next cycle. This approach improved reliability of the pick-up system without requiring

additional mechanical changes.

### 2.2.9 Electrical Systems

It was identified that a single battery would likely be insufficient to supply adequate current to all

components, including 4× N20 motors, 1× servo motor, 1× color sensor, and the required control

hardware. This assumption was based on prior experience in MSE 2202 labs, where the battery showed

performance issues under higher electrical loads, even when fully charged.

At the same time, the system architecture required the use of two ESP32 microcontrollers. This was due

to difficulties in merging the driving/navigation code with the sorting system code, which led to unreliable

behavior when combined. To address this, the systems were separated, with each ESP32 responsible for a specific subsystem. While this introduced additional weight and negatively impacted Objective O-3, it

was a necessary trade off to ensure reliable system operation within the project timeline.

As a result of both the increased electrical load and system separation, a dual battery configuration was

implemented. One battery powered 1× ESP32 and 2× N20 motors, while the second battery powered 1×

ESP32, 2× N20 motors, the servo motor, and the color sensor. This distribution reduced the load on each

battery and improved overall.

### 3 Conclusion


Figure 18: Technical Drawing of Final Design

The final design (Showcase Vehicle v2) had overall dimensions of 482 × 192 × 255 mm and a net weight

of approximately 900 g, consisting of 17 custom 3D printed components. The project followed an iterative design approach, where early design shortcomings were identified through testing and addressed

in subsequent iterations.


Figure 19: Implementation of Final Design

Overall performance at the showcase was below expectation, although most objectives and constraints

were met. The primary limitation was in navigation. The vehicle was not able to operate fully

autonomously, as it could not reliably return to the collection bin. Human assistance was required to

reposition the bin for successful eraser deposition, resulting in a failure to meet constraint C-7 (autonomy)

and Objective O-4 (navigation accuracy). This limitation was primarily due to the late stage shift to a time

based control strategy, which introduced positional error and reduced reliability.

Despite this, the mechanical systems performed well. The pick-up system operated consistently, and after

multiple design iterations, was able to reliably collect erasers without jamming. The sorting system was a

major success, achieving 100% sorting accuracy during the showcase. This strongly satisfied Objective

O-2, where sorting accuracy was prioritized over total collection quantity due to scoring penalties.

Significant improvements were also made in manufacturability, serviceability, and assembly. The transition to a modular design using M3 fasteners and heat-set inserts improved Objectives O-7 and O-8

by allowing components to be easily assembled, disassembled, and replaced without damage.

Standardization across subsystems (Objective O-9) reduced integration issues and improved collaboration

between team members. Objective O-6 (cost) was also met effectively. The final design used

approximately 210 g of PETG filament (~$3.78), along with 41 heat-set inserts (~$4.47) and 43 M3

screws (~$0.73), resulting in a total external cost of approximately $8.98. No additional electronic

components beyond those provided in the MSE 2202 lab kit were required. This kept the system well

within budget while maintaining functionality.

Overall, the project demonstrated a strong application of iterative engineering design. While full

autonomy was not achieved, the final system met most functional requirements and provided a reliable

and well integrated solution for eraser collection and sorting within the given constraints.

### 4.1.0 Mechanical Improvements

The pick-up mechanism should be validated early using real test conditions. The failure of the stick based

system was a major design oversight, as it relied on incorrect assumptions about material interaction. The

eraser coating prevented reliable adhesion, which was only discovered after significant design effort.

Future designs should prioritize early validation of contact based mechanisms and favor more passive,

geometry based solutions that are less sensitive to material properties.

### 4.2 Electrical & Software Improvements

The navigation system was the primary limitation of the final design. Future work should focus on

implementing a feedback based navigation system rather than relying on time based control. Even a simple closed loop system using encoders, line tracking, or boundary sensing would significantly improve

positional accuracy and allow the system to meet autonomy requirements.

From a system integration perspective, the need to split control across two ESP32 units indicates that

software architecture should be considered earlier. A more modular code structure or defined

communication protocol between subsystems could allow for integration on a single microcontroller,

reducing system complexity and weight.

### 4.3 Project Structure Improvements

One major limitation of the project was the lack of score based design evaluation during development.

While scoring criteria were analyzed early on, they were not actively used to guide design decisions.

Incorporating score prediction throughout the design process would allow for more informed trade offs,

particularly between weight, speed, and sorting performance.

Additionally, insufficient time was allocated after manufacturing for testing and iteration. This resulted in

rushed design changes and limited optimization. Future project timelines should allocate a dedicated

buffer for post-manufacturing testing and refinement, allowing for more controlled iterations and better

informed design decisions.

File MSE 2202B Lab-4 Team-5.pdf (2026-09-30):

# GROUP-5 LAB SECTION-4 MILESTONE-1

Members: Jason Pan, Liam Thomas McFadden, Anurag Aggarwal, Alan Sanjit
Problem Statement:
Resource extraction operations in hazardous environments need a way to autonomously navigate unknown terrain to identify and retrieve high-value objects (erasers), especially where long distance communication is unreliable. Thus, the objective of this project is to design and build an autonomous mobile robot capable of collecting pencil erasers from a defined area, separating them by colour, and returning them to a base location within a fixed time limit.

Constraints & Ways to Measure:
ID | Constraints | How to Measure
1. Size | | The robot must be able to fit in the MSE lab locker.
2. Sorting of Erasers | | The picked-up erasures must be sorted either on the robot or on a stationary sorting system, and must be done based on wavelength (colour)
3. Navigation | | The robot must be able traverse the area of operations without any hindrance or help from external sources.
4. Power/Battery | | The robot must be able to perform its entire task on a single charge of the batteries used, and the batteries used must not be modified.
5. Weight Drivable | | The robot must be able to move on its own weight and be light enough to be carried by a human (< 3 kg).
6. | Time-Efficient | Perform the entire operation within the limit of 2 minutes
7. Autonomous | | Operations must be performed without any human intervention or wireless communication.
8. Budget | | The overall cost of components for the robot, excluding components provided by the MSE 2202 lab kit, must not exceed $50. The overall cost for FDM and laser cutting must not exceed $20.
9. Durability | | The robot must be able to perform its task without the expense of its components. The robot must be able to perform the entire operation > 50 times without any need for component replacement.
10. Manufacturability | | The robot must be manufactured using available materials/components. This includes 4x MSE 2202 lab kit, FDM printed ABS/PETG/PLA components, and external components adhering to the budget constraint.

- Our design was developed directly around the defined system constraints to ensure measurable feasibility and performance. Size, weight, and manufacturability limits required the robot to fit within the MSE lab locker, remain under 3 kg, and be built using approved lab materials and FDM printing. Power and autonomy constraints required the system to complete the entire task on a single battery charge without human intervention or wireless assistance. Budget and durability limits further ensured the solution remained cost-effective while reliably performing at least 50 full operation cycles within the two-minute time requirement.

Objectives & Ways to measure:
ID | Objectives | How to Measure
1. | Simplicity of Design | The robot should be made with a minimum no. of components to increase reliability and durability
2. Sorting Accuracy & | Amount | Sort accuracy (the sorting between high-value and low-value erasers) should be > 85%.
3. Efficient Weight | Distribution | The robot should be balanced and must not stumble under its own weight.
4. | Navigation Accuracy | Should traverse the operation without losing sight of goals and have at least 90% success rate on test runs.
5. | Efficient UI | Clear indication of each process step and a failsafe in case of incidents or wrong performance of the task
6 | Budget | The total cost of external components should be < $20 provided by the project.
- Our design objectives focused on achieving high performance while maintaining simplicity and cost control. The system was engineered with a minimal number of components to improve reliability, while targeting over 85% sorting accuracy and at least 90% navigation success rate across multiple trials. Careful weight distribution ensured stable movement without imbalance or stalling during operation. Additionally, an efficient and clear user interface was implemented with process indication and fail-safe mechanisms, all while maintaining external component costs below the $20 budget constraint.

Rough Concept Generation:
ID | Concept | Readiness (Keep/Drop)

Reasoning

| | Robot Movement
1. | Gears with Tracks | Keep
2. | Aftermarket Rubber Wheels | Keep
3. Self-Manufactured 3D Printed | Wheels + Rubber Band Tires | Keep

Chassis Design

1. | 4 Wheel Drive | Keep
2. | 2 Wheel Drive | Keep
| S Wheel Drive + Dedicated Steering | Drop | Too complex with limited benefits.

Eraser Sorting

1. Conveyor Belt + 2 Lane Knocking | System | Keep
2. | Steep Slide with Hatch System | Keep
3. | Slide With Sorting Wheel | keep
4. Angle Slide with Sensor Knocking | System | Drop | It requires very precise timing and multisystem cooperation.

Eraser Drop Mechanism

1. | Slide | Keep
2. | Conveyor Belt | Drop | Require too much power and components
3. | Gate | Keep

Eraser Pick Up Sensing

1. | Camera | Drop | ESP32 does not have enough computational resources for image processing.
2. | UltraSonic Sensor | Keep
3. | Infrared Sensor | Keep

4. | UltraSonic + Infrared Sensor | Keep

Eraser Pick Up Mechanism

1. | Scoop pick-up | keep
2. | Sticky Conveyor Belt | Drop | The Stickiness might lose its effectiveness over time
3. | Claw | keep
4. | Vacuum Suction | Drop | Require many additional components on the robot
5. | Stabbing needle arm | Drop | Requires too much precision, too slow
6. | Scoop pick-up + Gate | Keep
- During rough concept generation, multiple movement, sorting, sensing, and pick-up mechanisms were evaluated based on complexity, power consumption, reliability, and integration feasibility. Concepts were kept if they provided clear functional benefits while remaining simple to implement within hardware and software limitations. Designs were dropped when they introduced excessive mechanical complexity, required high computational resources, or demanded precise multi-system coordination with limited performance improvement. Overall, priority was given to energy-efficient, lightweight, and modular solutions that align with system constraints and practical implementation within the project scope.

Go/No-Go Matrix:


- The final concept screening matrix evaluated each subsystem against key constraints, including size, power consumption, autonomy, budget, durability, and manufacturability. Concepts were marked “Go” when they met performance requirements without introducing excessive mechanical or software complexity. At the same time “No-Go” options were eliminated due to high power demand, spatial constraints, or synchronization challenges. “Maybe” selections reflect feasible solutions that carry moderate risks in durability, timing precision, or fabrication complexity. Overall, the matrix guided the selection of energy-efficient, lightweight, and practically implementable subsystems aligned with project constraints and performance objectives.

Pugh Matrix for Normalizing Weights:


- An Analytical Hierarchy Process (AHP) matrix was used to determine the relative importance of each design objective through pairwise comparisons. Sorting Accuracy & Amount and Budget received the highest normalized weightings (0.27 each), indicating they were considered the most critical factors in system performance and feasibility. Navigation Accuracy followed with a weighting of 0.22, reflecting its importance in ensuring reliable task completion. Simplicity of Design and Efficient Weight Distribution were moderately weighted (0.12 each), while Efficient UI was assigned the lowest priority (0.02), as it does not directly impact core system functionality.

Pugh Matrix:


- A weighted decision matrix was used to evaluate each concept against the prioritized objectives, applying the normalized weightings to generate final performance scores. The 2 Wheel Drive concept achieved the highest overall score (1.61), followed by Slide with Sorting Wheel (1.30) and Self-Manufactured 3D Printed Wheels with Rubber Band Tires (0.98), indicating strong alignment with the most critical objectives. Concepts such as Claw (-0.72) and Gears with Tracks (-0.36) scored negatively, reflecting trade-offs in complexity, cost, or efficiency relative to project priorities. The results confirm that simpler, lightweight, and cost-efficient mechanisms provide the strongest overall performance within the defined constraints.

Milestone 1 Design Conclusion:
The robot would be driven using two N20 motors provided within the MSE2202 lab kit. The motors would be attached to custom made wheels with rubber brands serving as tires for grip. An ultrasonic sensor and an infrared sensor would be used together to detect the objects and a scoop pick up system would be used to pick up the erasers actuated using one servo provided in the MSE 2202 lab kit. The sorting system will be onboard the robot and consists of a slide into a sorting wheel also driven by a servo also from the MSE 22202 lab kit. The sorting of erasers would be sensed using an infrared sensor to differentiate colours. Finally, the chassis will be designed to accommodate all subsystems of the robot and will be designed in ONSHAPE alongside any subsystem mechanism requiring custom components. Any CAD designs will bve manufactured using 3D printed PETG through a 3D printer belonging to one of the group members.

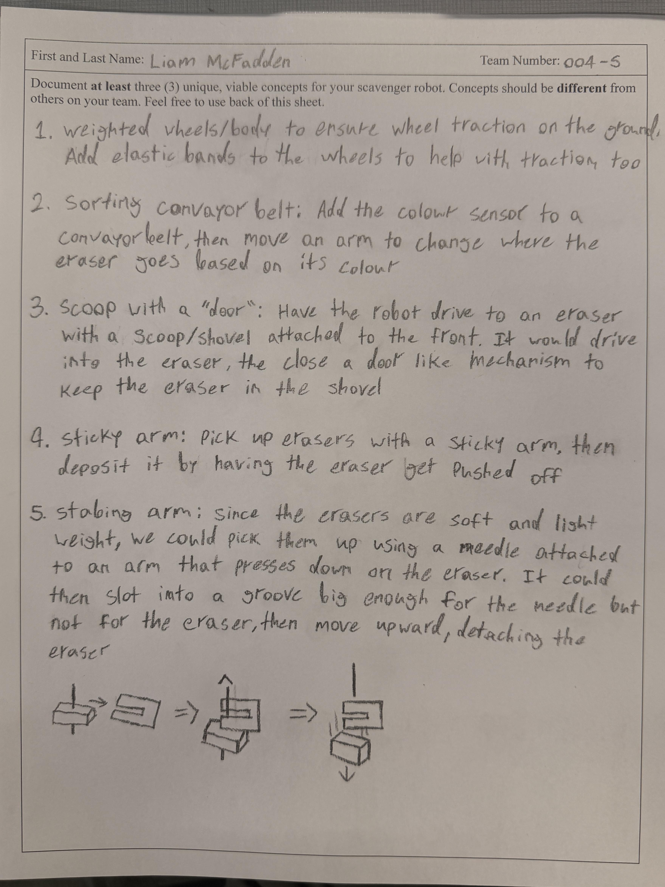
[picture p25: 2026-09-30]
Liam Feb 3 exercise.JPG

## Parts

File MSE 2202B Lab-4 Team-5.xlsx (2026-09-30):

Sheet: Sheet1
ID | Concepts | Size | Sorting of Erasers | Navigation | Power/Battery | Weight Drivable | Time-Efficient | Autonomous | Budget | Durability | Manufacturability | Reasoning
1 | Gears with Tracks | Go | N/A | Go | N/A | Go | N/A | N/A | Go | Go | Maybe | - Requires precise alignment, tension control, and additional mechanical components, increasing fabrication complexity. - Higher material cost reduces overall efficiency and mobility compared to simpler wheel-based systems.
2 | Aftermarket Rubber Wheels | Go | N/A | Go | N/A | Go | Go | N/A | Maybe | Go | Go | - Purchasing pre-manufactured components increases total project cost. - Cost may not justify marginal traction improvement over lower-cost alternatives.
3 | Self-Manufactured 3D Printed Wheels + Rubber Band Tires | Go | N/A | Go | N/A | Go | N/A | N/A | Go | Maybe | Go | - 3D printed materials may wear down under continuous friction and load. - Rubber bands can stretch or degrade, reducing long-term reliability.
4 | 4 Wheel Drive | Go | N/A | Go | No Go | Go | Go | No Go | Go | Go | Go | - Requires synchronization between two ESP32 boards, increasing software complexity. - Coordinating encoder feedback and motor control adds unnecessary programming overhead.
5 | 2 Wheel Drive | Go | N/A | Go | Go | Maybe | Maybe | Go | Go | Go | Go | - Uneven weight distribution may reduce traction and stability. - Limited drive contact points can affect load handling performance.
6 | Conveyor Belt + 2 Lane Knocking System | No Go | Go | Go | Go | Go | Maybe | Go | Maybe | Maybe | Maybe | - System footprint exceeds locker size constraints. - Additional belt and lane structure increases spatial requirements.
7 | Steep Slide with Hatch System | Go | Go | N/A | Go | Go | Go | Go | Go | Go | Go
8 | Slide With Sorting Wheel | Go | Go | N/A | Go | Go | Maybe | Go | Go | Go | Go | - Sorting wheel timing must align precisely with item arrival. - Rotational misalignment may reduce throughput efficiency.
9 | Slide | Go | N/A | N/A | Go | Go | Go | Go | Go | Go | Go
10 | Gate | Go | N/A | N/A | Go | Go | Maybe | Go | Go | Go | Go | - Servo actuation introduces delay during opening and closing cycles. - Mechanical lag may slow repeated sorting operations.
11 | UltraSonic Sensor | Go | Go | Go | Go | Go | Go | Go | Go | Go | N/A
12 | Infrared Sensor | Go | Go | No Go | Go | Go | Go | Go | Maybe | Go | N/A | - Lab IR sensor is unreliable for accurate distance measurement. - Readings are affected by ambient light and surface reflectivity.-
13 | UltraSonic + Infrared Sensor | Go | Go | Go | Go | Go | Go | Go | Go | Go | N/A
14 | Scoop pick-up | Go | Go | N/A | Go | Go | Go | Go | Go | Go | Go
15 | Claw | Go | Go | N/A | Go | Maybe | Maybe | Go | Go | Maybe | Maybe | - Requires precise servo calibration and grip control. - Complex geometry increases fabrication difficulty.
16 | Scoop pick-up + Gate | Go | Go | N/A | Go | Go | Maybe | Go | Go | Go | Go | - Combining scoop and gate may introduce redundant handling steps. - Additional mechanism coordination increases cycle time.

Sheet: Sheet2
Objectives | Simplicity of Design | Sorting Accuracy & Amount | Efficient Weight Distribution | Navigation Accuracy | Efficient UI | Budget | Total | Normalized Weighting | Legend
Simplicity of Design | 1.00 | 0.14 | 1.00 | 0.20 | 9.00 | 0.14 | 11.49 | 0.12 | Relative Importance | Score
Sorting Accuracy & Amount | 7.00 | 1.00 | 7.00 | 1.00 | 9.00 | 1.00 | 26.00 | 0.27 | Exceptionally Less | 2026-01-09
Efficient Weight Distribution | 1.00 | 0.14 | 1.00 | 0.20 | 9.00 | 0.33 | 11.68 | 0.12 | Much Less | 2026-01-07
Navigation Accuracy | 5.00 | 1.00 | 5.00 | 1.00 | 9.00 | 0.20 | 21.20 | 0.22 | Less | 2026-01-05
Efficient UI | 2026-01-09 | 2026-01-09 | 2026-01-09 | 2026-01-09 | 1.00 | 0.11 | 1.56 | 0.02 | Slightly Less | 2026-01-03
Budget | 7.00 | 1.00 | 3.00 | 5.00 | 9.00 | 1.00 | 26.00 | 0.27 | Equally Important | 1.00
 |  |  |  |  |  |  | 97.92 | 1.00 | Slightly More | 3.00
 |  |  |  |  |  |  |  |  | More | 5.00
 |  |  |  |  |  |  |  |  | Much More | 7.00
 |  |  |  |  |  |  |  |  | Exceptionally More | 9.00

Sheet: Sheet3
# | Objective | How to Measure | Weight (higher number is more important) | Gears with Tracks | Aftermarket Rubber Wheels | Self-Manufactured 3D Printed Wheels + Rubber Band Tires | 2 Wheel Drive | Steep Slide with Hatch System | Slide With Sorting Wheel | Slide | Gate | UltraSonic Sensor | UltraSonic + Infrared Sensor | Scoop pick-up | Claw
1 | Simplicity of Design |  | 0.12 | -1 | 2 | 1 | 1 | 1 | 2 | 2 | -1 | 0 | -2 | 2 | -1
2 | Sorting Accuracy & Amount |  | 0.27 | 0 | 0 | 0 | 2 | 2 | 2 | 0 | 0 | 0 | 0 | 0 | 0
3 | Efficient Weight Distribution |  | 0.12 | 2 | 1 | 1 | 0 | -1 | 0 | 0 | -1 | 0 | 0 | -1 | -1
4 | Navigation Accuracy |  | 0.22 | -1 | 1 | 1 | 2 | 0 | 0 | 0 | 0 | 0 | 1 | 1 | -1
5 | Efficient UI |  | 0.02 | 0 | 0 | 0 | 0 | 0 | 0 | 0 | 0 | 0 | 2 | 1 | 0
6 | Budget |  | 0.27 | -1 | -1 | 2 | 2 | 1 | 2 | 2 | 1 | 2 | 2 | 2 | -1
 | Results
 | Weighted Totals |  |  | -0.360848139 | 0.304824277 | 0.9841136039 | 1.612436779 | 0.794644015 | 1.296718973 | 0.7656594475 | 0.0289845675 | 0.5310595254 | 0.5447412787 | 0.8788094929 | -0.7185838413
 | Apply conditional formatting to "Totals" row for better visualization
 | Making sure objectives are solution independent!
 | Wherever possible include a note indicating how that objective (desirable attribute or feature of the solution) could be measured or evaluated and thus compared across all solution candidates.
 | Don’t forget things like convenience, efficiency, size, portability, cost, durability, etc.
 |  |  |  |  | e

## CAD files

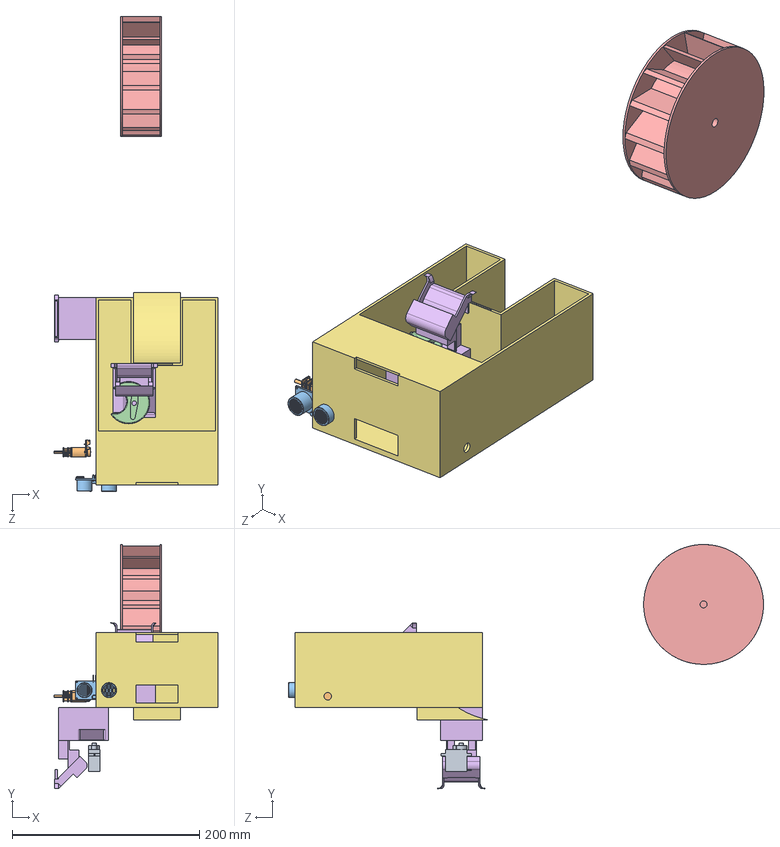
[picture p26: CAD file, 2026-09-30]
Model_Parts/Titan.SLDASM
174.7 x 260.3 x 506.8 mm
2202_Chasis_Dimensioned
Ramp_With_Catridge x 2
Scoop Wheel
Sorter_Wheel
HC-SR04-UltrasonicSensor v7
n20 motor with encoder
servo 25

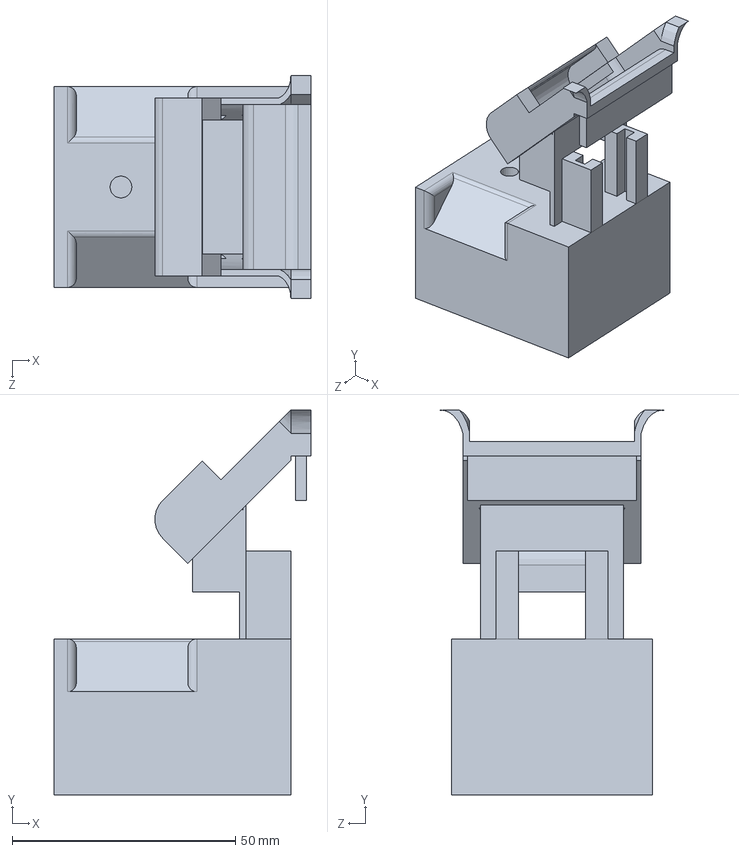
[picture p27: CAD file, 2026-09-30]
Model_Parts/Ramp_With_Catridge.SLDPRT
57.6 x 86.3 x 50.0 mm

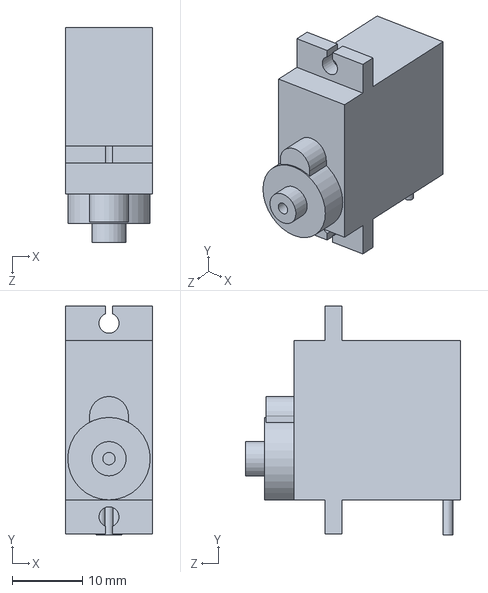
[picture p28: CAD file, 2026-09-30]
Model_Parts/servo 25.SLDPRT
12.4 x 32.6 x 30.6 mm

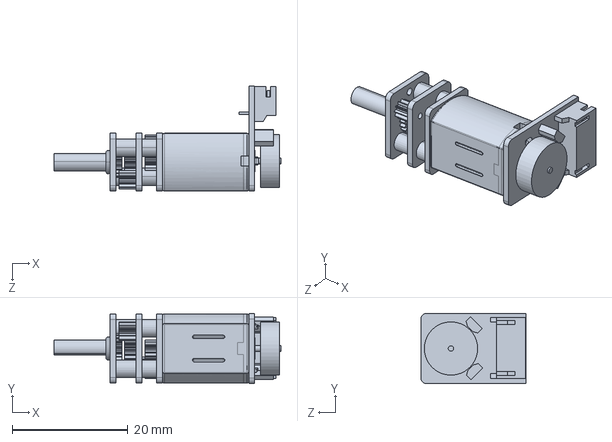
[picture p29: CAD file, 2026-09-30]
Model_Parts/n20 motor with encoder.SLDPRT
39.2 x 12.2 x 18.2 mm

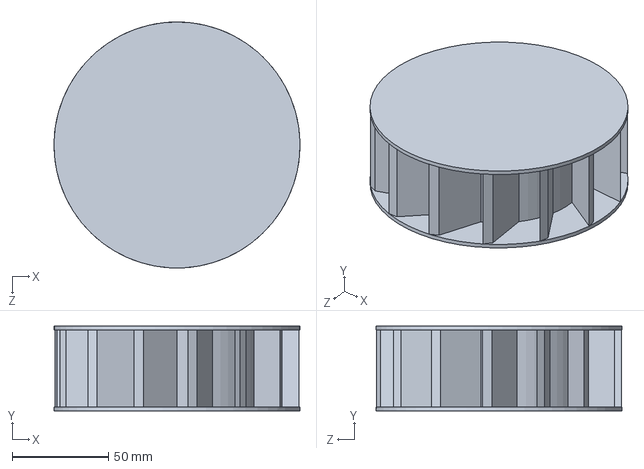
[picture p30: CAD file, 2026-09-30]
Model_Parts/Scoop Wheel.SLDPRT
127.9 x 44.0 x 127.9 mm

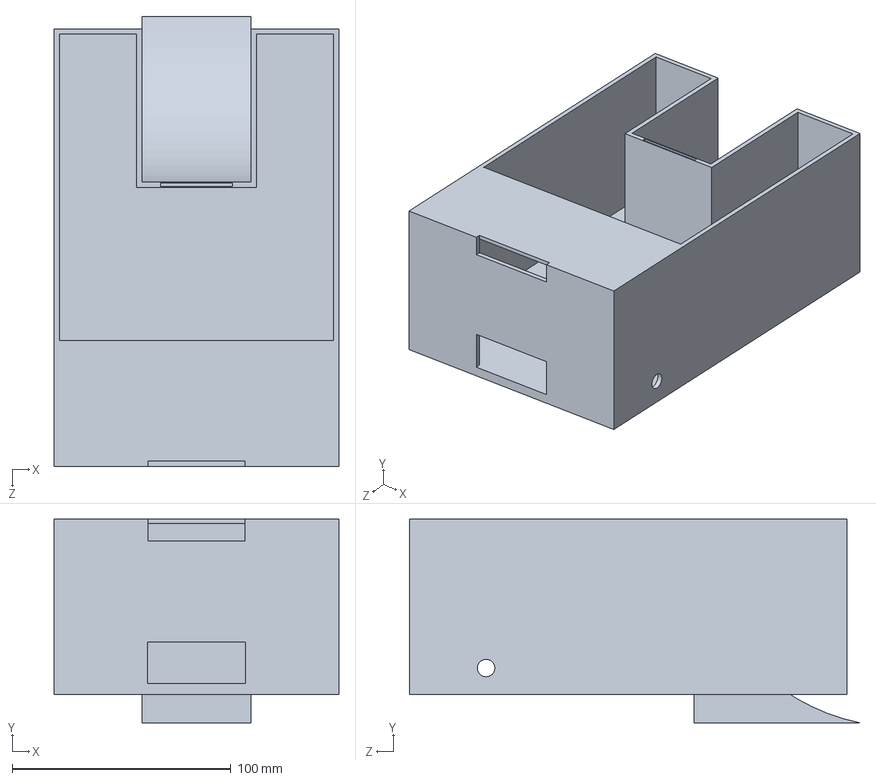
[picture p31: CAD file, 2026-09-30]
Model_Parts/2202_Chasis_Dimensioned.SLDPRT
130.0 x 93.0 x 205.6 mm

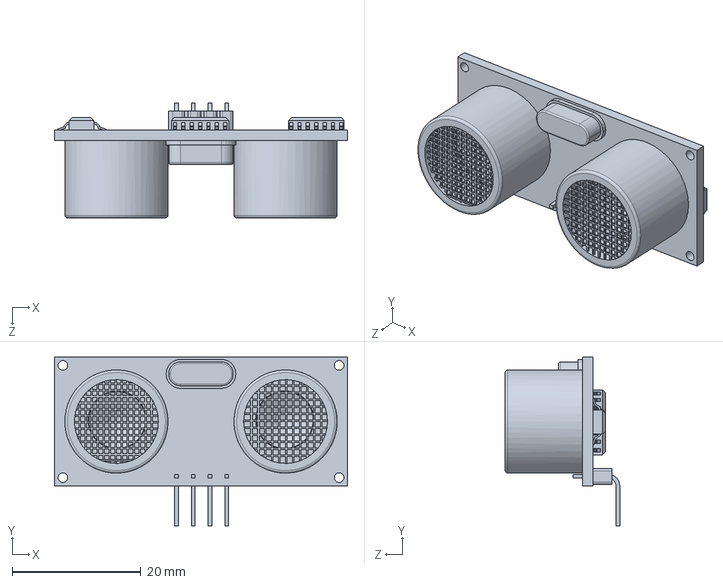
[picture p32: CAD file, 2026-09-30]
Model_Parts/HC-SR04-UltrasonicSensor v7.SLDPRT
45.4 x 26.2 x 17.8 mm

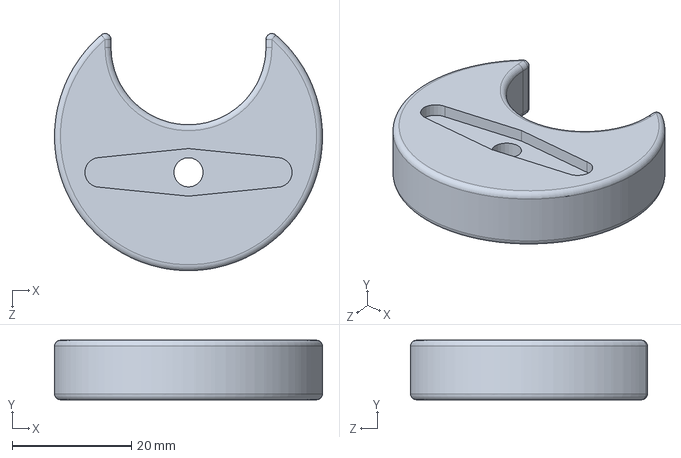
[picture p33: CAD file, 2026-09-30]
Model_Parts/Sorter_Wheel.SLDPRT
45.0 x 10.0 x 39.8 mm

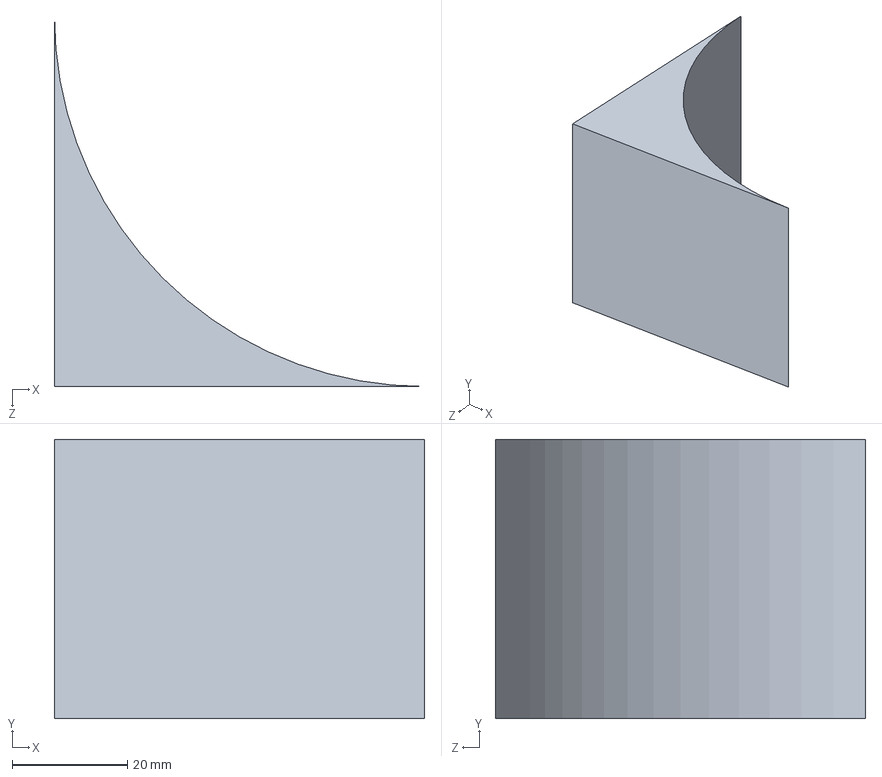
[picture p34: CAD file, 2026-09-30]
Model_Parts/Ramp.SLDPRT
64.2 x 48.5 x 64.2 mm

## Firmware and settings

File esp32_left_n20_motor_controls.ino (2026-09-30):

//Code for the Left ESP 32. Responsible for all n20 motor controls.

#include <Arduino.h>
#include <Adafruit_NeoPixel.h>

// Function declarations
void doHeartbeat();
void setMotor(int dir, int pwm, int in1, int in2);
void ARDUINO_ISR_ATTR buttonISR(void* arg);
void ARDUINO_ISR_ATTR encoderISR(void* arg);

// Button structure
struct Button {
  const int pin;                                                       // GPIO pin for button
  volatile uint32_t numberPresses;                                     // counter for number of button presses
  uint32_t nextPressTime;                                              // time of next allowable press in milliseconds
  volatile bool pressed;                                               // flag for button press event
};

// Encoder structure
struct Encoder {
  const int PinA;                                                      // GPIO pin for encoder Channel A
  const int PinB;                                                      // GPIO pin for encoder Channel B
  volatile long pos;                                                   // current encoder position
};

// Function declarations
void doHeartbeat();
void setMotor(int dir, int pwm, int in1, int in2);
void ARDUINO_ISR_ATTR buttonISR(void* arg);
void ARDUINO_ISR_ATTR encoderISR(void* arg);

// Constants
const int cHeartbeatInterval = 75;                                     // heartbeat update interval, in milliseconds
const int cSmartLED          = 23;                                     // when DIP switch S1-4 is on, SMART LED is connected to GPIO23
const int cSmartLEDCount     = 1;                                      // number of Smart LEDs in use
const long cDebounceDelay    = 170;                                    // switch debounce delay in milliseconds
const int cNumMotors         = 4;                                      // Number of DC motors
const int cIN1Pin[]          = {26, 16,25, 5};                               // GPIO pin(s) for IN1 for left and right motors (A, B)
const int cIN2Pin[]          = {27, 17,33,18};                               // GPIO pin(s) for IN2 for left and right motors (A, B)
const int cPWMRes            = 8;                                      // bit resolution for PWM
const int cMinPWM            = 150;                                    // PWM value for minimum speed that turns motor
const int cMaxPWM            = pow(2, cPWMRes) - 1;                    // PWM value for maximum speed
const int cPWMFreq           = 20000;                                  // frequency of PWM signal
const int cCountsRev         = 1096;                                   // encoder pulses per motor revolution
const int cPotPin            = 36;                                     // GPIO pin for drive speed potentiometer (A0)
const int cMotorEnablePin    = 39;                                     // GPIO pin for motor enable switch (DIP S1-1)
const int speed = 230;
int motionState = 0;                                                   // state variable for the motion finite-state machine
int motionState2 = 0;

//=====================================================================================================================
//
// IMPORTANT: The constants in this section need to be set to appropriate values for your robot. 
//            You will have to experiment to determine appropriate values.
const int cMotorAdjustment[] = {0, 0};                                 // PWM adjustment for motors to run closer to the same speed

// Variables
boolean motorsEnabled        = true;                                   // motors enabled flag
boolean timeUp3sec           = false;                                  // 3 second timer elapsed flag
boolean timeUp2secBigWheel           = false;                                  // 2 second timer elapsed flag
boolean timeUp25cm           = false;                                  // "move ~25cm" timer elapsed flag
uint32_t lastHeartbeat       = 0;                                      // time of last heartbeat state change
uint32_t curMillis           = 0;                                      // current time, in milliseconds
uint32_t timerCount3sec      = 0;                                      // 3 second timer count in milliseconds
uint32_t timerCount2secBigWheel      = 0;                                      // 2 second timer count in milliseconds
uint32_t timerCount25cm      = 0;                                      // timer count used to approximate 25cm movement
uint32_t robotModeIndex      = 0;                                      // robot operational state                              
uint32_t lastTime            = 0;                                      // last time of motor control was updated
uint32_t timerCount110sec = 0;
uint32_t timerCount10sec = 0;
boolean timeUp10sec = false;
boolean timeUp110sec = false;
Button modeButton            = {0, 0, 0, false};                       // NO pushbutton PB1 on GPIO 0, low state when pressed
/*
Encoder encoder[]            = {{35, 32, 0},                           // left encoder (A) on GPIO 35 and 32, 0 position 
                                {33, 25, 0}};                          // right encoder (B) on GPIO 33 and 25, 0 position
*/
uint8_t driveSpeed           = 0;                                      // motor drive speed (0-255)
uint8_t driveIndex           = 0;                                      // state index for run mode

// Declare SK6812 SMART LED object
//   Argument 1 = Number of LEDs (pixels) in use
//   Argument 2 = ESP32 pin number 
//   Argument 3 = Pixel type flags, add together as needed:
//     NEO_KHZ800  800 KHz bitstream (most NeoPixel products w/WS2812 LEDs)
//     NEO_KHZ400  400 KHz (classic 'v1' (not v2) FLORA pixels, WS2811 drivers)
//     NEO_GRB     Pixels are wired for GRB bitstream (most NeoPixel products)
//     NEO_RGB     Pixels are wired for RGB bitstream (v1 FLORA pixels, not v2)
//     NEO_RGBW    Pixels are wired for RGBW bitstream (NeoPixel RGBW products)
Adafruit_NeoPixel SmartLEDs(cSmartLEDCount, cSmartLED, NEO_RGB + NEO_KHZ800);

// Smart LED brightness for heartbeat
unsigned char LEDBrightnessIndex = 0; 
unsigned char LEDBrightnessLevels[] = {0, 0, 0, 5, 15, 30, 45, 60, 75, 90, 105, 120, 135, 
                                       150, 135, 120, 105, 90, 75, 60, 45, 30, 15, 5, 0};

uint32_t modeIndicator[6]    = {                                       // colours for different modes
  SmartLEDs.Color(255, 0, 0),                                          //   red - stop
  SmartLEDs.Color(0, 255, 0),                                          //   green - run
  SmartLEDs.Color(0, 0, 255),                                          //   blue - empty case
  SmartLEDs.Color(255, 255, 0),                                        //   yellow - empty case
  SmartLEDs.Color(0, 255, 255),                                        //   cyan - empty case
  SmartLEDs.Color(255, 0, 255)                                         //   magenta - empty case
};                                                                            

void setup() {
  Serial.begin(115200);                                                // Standard baud rate for ESP32 serial monitor

  // Set up SmartLED
  SmartLEDs.begin();                                                   // initialize smart LEDs object
  SmartLEDs.clear();                                                   // clear pixel
  SmartLEDs.setPixelColor(0, SmartLEDs.Color(0,0,0));                  // set pixel colours to black (off)
  SmartLEDs.setBrightness(0);                                          // set brightness [0-255]
  SmartLEDs.show();                                                    // update LED


  // setup motors with encoders
  for (int k = 0; k < cNumMotors; k++) {
    ledcAttach(cIN1Pin[k], cPWMFreq, cPWMRes);                         // setup INT1 GPIO PWM Channel
    ledcAttach(cIN2Pin[k], cPWMFreq, cPWMRes);                         // setup INT2 GPIO PWM Channel
    /*
    pinMode(encoder[k].PinA, INPUT);                                   // configure GPIO for encoder Channel A input
    pinMode(encoder[k].PinB, INPUT);                                   // configure GPIO for encoder Channel B input
    // configure encoder to trigger interrupt with each rising edge on Channel A
    attachInterruptArg(encoder[k].PinA, encoderISR, &encoder[k], RISING);
    */
  }

  // Set up push button
  pinMode(modeButton.pin, INPUT_PULLUP);                               // configure GPIO for mode button pin with internal pullup resistor
  attachInterruptArg(modeButton.pin, buttonISR, &modeButton, FALLING); // Configure ISR to trigger on low signal on pin
  
  pinMode(cPotPin, INPUT);                                             // set up drive speed potentiometer
  pinMode(cMotorEnablePin, INPUT);                                     // set up motor enable switch (uses external pullup)
}

void loop() {
  long pos[] = {0, 0};                                                 // current motor positions (snapshotted from ISR)
  int pot = 0;                                                         // raw ADC value from pot

  // store encoder position to avoid conflicts with ISR updates
  noInterrupts();                                                      // disable interrupts temporarily while reading
  /*
  for (int k = 0; k < cNumMotors; k++) {
      pos[k] = encoder[k].pos;                                         // read and store current motor position
  }
  */
  interrupts();                                                        // turn interrupts back on
 
  uint32_t curTime = micros();                                         // capture current time in microseconds
  if (curTime - lastTime > 1000) {                                     // run this "control tick" about every 1 ms
    lastTime = curTime;                                                // update start time for next control cycle

    // 3 second timer, counts 3000 milliseconds
    timerCount3sec += 1;                                               // increment 3 second timer count by 1 ms
    if (timerCount3sec > 3000) {                                       // check if 3000 ms have elapsed
      timerCount3sec = 0;                                              // reset 3 second timer count
      timeUp3sec = true;                                               // raise 3-second elapsed flag
    }  
   
    // 2 second timer, counts 2000 milliseconds
    timerCount2secBigWheel += 1;                                               // increment 2 second timer count by 1 ms
    if (timerCount2secBigWheel > 2000) {                                       // check if 2000 ms have elapsed
      timerCount2secBigWheel = 0;                                              // reset 2 second timer count
      timeUp2secBigWheel = true;                                               // raise 2-second elapsed flag
    }

    timerCount25cm += 1;                                               // increment the "distance approximation" timer by 1 ms
    if (timerCount25cm > 7000) {                                       // after ~7000 ms, assume we've moved ~25 cm
      timerCount25cm = 0;                                              // reset the 25 cm timer
      timeUp25cm = true;                                               // raise the "moved 25 cm" flag
    }

    timerCount10sec += 1;
    if (timerCount10sec > 20000) {
      timerCount10sec = 0;
      timeUp10sec = true;
    }

    timerCount110sec += 1;
    if (timerCount110sec > 40000) {
      timerCount110sec = 0;
      timeUp110sec = true;
    }

    if (modeButton.pressed) {                                          // Change mode on button press
      robotModeIndex++;                                                // move to next mode index
      robotModeIndex = robotModeIndex & 7;                             // keep mode index within 0..7
      timerCount3sec = 0;                                              // reset 3 second timer count
      timeUp3sec = false;                                              // clear 3 second elapsed flag
      timeUp25cm = false;                                              // clear 25cm flag on mode change
      timerCount25cm = 0;                                              // reset 25cm timer on mode change
      modeButton.pressed = false;                                      // consume the button press event
    }

    // check if drive motors should be powered
    motorsEnabled = !digitalRead(cMotorEnablePin);                     // read enable switch (active-low): true when switch is on
    
    // modes 
    // 0 = Default after power up/reset.           Robot is stopped
    // 1 = Press mode button once to enter.        Run robot
    // 2 = Press mode button twice to enter.       Add your code to do something 
    // 3 = Press mode button three times to enter. Add your code to do something 
    // 4 = Press mode button four times to enter.  Add your code to do something 
    // 5 = Press mode button five times to enter.  Add your code to do something 
    // 6 = Press mode button six times to enter.   Add your code to do something 
    switch (robotModeIndex) {

      case 0://Robot stopped. Press button to move to next case.
        setMotor(0, 0, cIN1Pin[0], cIN2Pin[0]);                        // stop left motor
        setMotor(0, 0, cIN1Pin[1], cIN2Pin[1]);                        // stop right motor
        setMotor(0, 0, cIN1Pin[2], cIN2Pin[2]);                        // stop left motor
        setMotor(0, 0, cIN1Pin[3], cIN2Pin[3]);                        // stop right motor
        driveIndex = 0;                                                 // reset drive index
        timerCount2secBigWheel = 0;                                            // reset 2 second timer count
        timeUp2secBigWheel = false;                                            // reset 2 second timer
        break;

      case 1://Runs big wheel + belt motor.
        if (motorsEnabled) {                                           // only run motion logic if motor enable switch is on
                                                                       // and run only if enabled
          // Read pot to update drive motor speed
          pot = analogRead(cPotPin);                                   // read analog potentiometer (0..4095)
          driveSpeed = map(pot, 0, 4095, cMinPWM, cMaxPWM);            // map pot to PWM drive range

#ifdef DEBUG_DRIVE_SPEED
          Serial.printf("Drive Speed: Pot R1 = %d, mapped = %d\n", pot, driveSpeed);
#endif
/*
#ifdef DEBUG_ENCODER_COUNTS
          Serial.printf("Encoders: Left = %ld, Right = %ld\n", pos[0], pos[1]);
#endif    
*/

          if (timeUp110sec) {
            setMotor(1, 255, cIN1Pin[0], cIN2Pin[0]);
          } else {
            setMotor(1, 0, cIN1Pin[0], cIN2Pin[0]);
          }

          
          //setMotor(1, 255, cIN1Pin[1], cIN2Pin[1]);
          switch (motionState) {                                       // motion state machine for case 1 behavior
            case 0:
              setMotor(1, 255, cIN1Pin[1], cIN2Pin[1]);//drive left motor forward at fixed PWM
              if (timeUp2secBigWheel) {
                timeUp2secBigWheel = false;
                timerCount2secBigWheel = 0;
                motionState = 1;
              }
              //setMotor(1, driveSpeed, cIN1Pin[0], cIN2Pin[0]);

              //setMotor(1, driveSpeed, cIN1Pin[1], cIN2Pin[1]);//drive right motor reverse at fixed PWM (spin/turn behavior)
              break;
            case 1:
              setMotor(-1, 255, cIN1Pin[1], cIN2Pin[1]);
              if (timerCount2secBigWheel > 500) {                       // once an additional 500ms have passed...
                timerCount2secBigWheel = 0;                             // reset the timer
                motionState = 0;
              }
              break;            
          }
          
          switch (motionState2) {
              case 0:
                setMotor(1, driveSpeed, cIN1Pin[2], cIN2Pin[2]);
                setMotor(1, driveSpeed, cIN1Pin[3], cIN2Pin[3]);
                if (timeUp10sec) {
                  motionState2 += 1;
                  timerCount10sec = 0;
                  timeUp10sec = false;
                  setMotor(2, 0, cIN1Pin[2], cIN2Pin[2]);
                  setMotor(2, 0, cIN1Pin[3], cIN2Pin[3]);
                }

                Serial.println(timerCount10sec);

              break;

              case 1:
              Serial.println("Success");
                setMotor(-1, driveSpeed, cIN1Pin[2], cIN2Pin[2]);
                setMotor(-1, driveSpeed, cIN1Pin[3], cIN2Pin[3]);
                
                if (timerCount10sec > 15000) {
                  motionState2 += 1;
                  timerCount10sec = 0;
                }
              break;

              case 2:
                setMotor(2, 0, cIN1Pin[2], cIN2Pin[2]);
                setMotor(2, 0, cIN1Pin[3], cIN2Pin[3]);
              break;
          }
          
        }
        break;

      case 2: //add your code to do something
        robotModeIndex = 0;                                            //  !!!!!!!  remove if using the case
        break;

      case 3: //add your code to do something 
        robotModeIndex = 0;                                            //  !!!!!!!  remove if using the case
        break;

      case 4: //add your code to do something 
        robotModeIndex = 0;                                            //  !!!!!!!  remove if using the case
        break;

      case 5: //add your code to do something 
        robotModeIndex = 0;                                            //  !!!!!!!  remove if using the case
        break;

      case 6: //add your code to do something 
        robotModeIndex = 0;                                            //  !!!!!!!  remove if using the case
        break;
    }
  }

  doHeartbeat();                                                       // update heartbeat LED
}

// update heartbeat LED
void doHeartbeat() {
  curMillis = millis();                                                // get the current time in milliseconds
  // check to see if elapsed time matches the heartbeat interval
  if ((curMillis - lastHeartbeat) > cHeartbeatInterval) {
    lastHeartbeat = curMillis;                                         // update the heartbeat time for the next update
    LEDBrightnessIndex++;                                              // shift to the next brightness level
    if (LEDBrightnessIndex >= sizeof(LEDBrightnessLevels)) {           // if all defined levels have been used
      LEDBrightnessIndex = 0;                                          // reset to starting brightness
    }
    SmartLEDs.setBrightness(LEDBrightnessLevels[LEDBrightnessIndex]);  // set brightness of heartbeat LED
    SmartLEDs.setPixelColor(0, modeIndicator[robotModeIndex]);         // set pixel colors to = mode 
    SmartLEDs.show();                                                  // update LED
  }
}


// send motor control signals, based on direction and pwm (speed)
void setMotor(int dir, int pwm, int in1, int in2) {
  if (dir == 1) {                                                      // forward
    ledcWrite(in1, pwm);
    ledcWrite(in2, 0);
  }
  else if (dir == -1) {                                                // reverse
    ledcWrite(in1, 0);
    ledcWrite(in2, pwm);
  }
  else {                                                               // stop
    ledcWrite(in1, 0);
    ledcWrite(in2, 0);
  }
}

// button interrupt service routine
// argument is pointer to button structure, which is statically cast to a Button structure, 
// allowing multiple instances of the buttonISR to be created (1 per button)
void ARDUINO_ISR_ATTR buttonISR(void* arg) {
  Button* s = static_cast<Button*>(arg);                               // cast pointer to static structure

  uint32_t pressTime = millis();                                       // capture current time
  if (pressTime > s->nextPressTime) {                                  // if enough time has passed to consider a valid press
    s->numberPresses += 1;                                             // increment button press counter
    s->pressed = true;                                                 // indicate valid button press state
    s->nextPressTime = pressTime + cDebounceDelay;                     // update time for next valid press
  }  
}

// encoder interrupt service routine
// argument is pointer to an encoder structure, which is statically cast to a Encoder structure, allowing multiple
// instances of the encoderISR to be created (1 per encoder)
/*
void ARDUINO_ISR_ATTR encoderISR(void* arg) {
  Encoder* s = static_cast<Encoder*>(arg);                             // cast pointer to static structure
  
  int b = digitalRead(s->PinB);                                        // read state of Channel B
  if (b > 0) {                                                         // high, leading Channel A
    s->pos++;                                                          // increase position
  }
  else {                                                               // low, lagging Channel A
    s->pos--;                                                          // decrease position
  }
}
*/

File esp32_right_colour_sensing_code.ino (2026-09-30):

//
// MSE 2202 TCS34725 colour sensor example
// Updated to:
// - average multiple readings
// - normalize RGB values
// - detect color names using thresholds
// - control SG90 sorter servo
//
// Language: Arduino (C++)
// Target:   ESP32
//

#define PRINT_COLOUR

#include <Arduino.h>
#include <Adafruit_NeoPixel.h>
#include <Wire.h>
#include <SPI.h>
#include "Adafruit_TCS34725.h"
#include <ESP32Servo.h>

// Function declarations
void doHeartbeat();
String detectColor(float rn, float gn, float bn, uint16_t c);
void updateSorter(const String& detectedColor);

// Constants
const int cHeartbeatInterval = 75;
const int cSmartLED          = 23;
const int cSmartLEDCount     = 1;
const int cSDA               = 18;
const int cSCL               = 19;
const int cTCSLED            = 14;
const int cLEDSwitch         = 34;

// Servo constants
const int cServoPin          = 22;

// Set this to your known center value
const int cServoCenterUS     = 1600;

// Approximate microsecond change for 90 degrees from center
// Tune this value if needed: try 450, 500, 550, etc.
const int cServo90OffsetUS   = 1050;

// Left/right positions are symmetric around center
const int cServoLeftUS       = cServoCenterUS + cServo90OffsetUS;
const int cServoRightUS      = cServoCenterUS - cServo90OffsetUS;

const int cServoMoveDelayMs  = 400;

// Averaging settings
const int cNumSamples        = 10;
const int cSampleDelayMs     = 5;

// Variables
boolean heartbeatState       = true;
unsigned long lastHeartbeat  = 0;
unsigned long curMillis      = 0;
unsigned long prevMillis     = 0;

// Sorter state
String lastSorterDirection   = "CENTER";

// Declare SK6812 SMART LED object
Adafruit_NeoPixel SmartLEDs(cSmartLEDCount, cSmartLED, NEO_RGB + NEO_KHZ800);

// Servo object
Servo sorterServo;

// Smart LED brightness for heartbeat
unsigned char LEDBrightnessIndex = 0;
unsigned char LEDBrightnessLevels[] = {
  0, 0, 0, 5, 15, 30, 45, 60, 75, 90, 105, 120, 135,
  150, 135, 120, 105, 90, 75, 60, 45, 30, 15, 5, 0
};

// TCS34725 colour sensor
Adafruit_TCS34725 tcs =
  Adafruit_TCS34725(TCS34725_INTEGRATIONTIME_2_4MS, TCS34725_GAIN_4X);

bool tcsFlag = 0;

void setup() {
  Serial.begin(115200);

  // Set up SmartLED
  SmartLEDs.begin();
  SmartLEDs.clear();
  SmartLEDs.setPixelColor(0, SmartLEDs.Color(0, 0, 0));
  SmartLEDs.setBrightness(0);
  SmartLEDs.show();

  Wire.setPins(cSDA, cSCL);
  pinMode(cTCSLED, OUTPUT);
  pinMode(cLEDSwitch, INPUT_PULLUP);

  // Set up sorter servo
  sorterServo.setPeriodHertz(50);
  sorterServo.attach(cServoPin, 500, 2400);
  sorterServo.writeMicroseconds(cServoCenterUS);
  delay(500);
  sorterServo.detach();

  // Connect to TCS34725 colour sensor
  if (tcs.begin()) {
    Serial.println("Found TCS34725 colour sensor");
    tcsFlag = true;
  } else {
    Serial.println("No TCS34725 found ... check your connections");
    tcsFlag = false;
  }
}

void loop() {
  uint16_t r = 0, g = 0, b = 0, c = 0;

  digitalWrite(cTCSLED, !digitalRead(cLEDSwitch));

  if (tcsFlag) {
    // Average multiple samples
    uint32_t rSum = 0, gSum = 0, bSum = 0, cSum = 0;

    for (int i = 0; i < cNumSamples; i++) {
      uint16_t rt, gt, bt, ct;
      tcs.getRawData(&rt, &gt, &bt, &ct);
      rSum += rt;
      gSum += gt;
      bSum += bt;
      cSum += ct;
      delay(cSampleDelayMs);
    }

    r = rSum / cNumSamples;
    g = gSum / cNumSamples;
    b = bSum / cNumSamples;
    c = cSum / cNumSamples;

    float sum = r + g + b;

    if (sum > 0) {
      float rn = r / sum;
      float gn = g / sum;
      float bn = b / sum;

      String detectedColor = detectColor(rn, gn, bn, c);

      updateSorter(detectedColor);

#ifdef PRINT_COLOUR
      Serial.printf("Raw  R:%4d G:%4d B:%4d C:%4d   ", r, g, b, c);
      Serial.printf("Norm R:%.3f G:%.3f B:%.3f   ", rn, gn, bn);
      Serial.print("Detected: ");
      Serial.print(detectedColor);
      Serial.print("   Sorter: ");
      Serial.println(lastSorterDirection);
#endif
    } else {
      Serial.println("No valid colour reading");
    }
  }

  doHeartbeat();
}

// Detect color from normalized RGB + clear channel
String detectColor(float rn, float gn, float bn, uint16_t c) {

  // BLACK
  if (c < 40) {
    return "BLACK";
  }

  // WHITE
  if (c > 300 && abs(rn - gn) < 0.08 && abs(gn - bn) < 0.08) {
    return "WHITE";
  }

  // GREEN
  if (gn > 0.45) {
    return "GREEN";
  }

  // BLUE
  if (bn > 0.45 && c > 60) {
    return "BLUE";
  }

  // YELLOW
  if (rn > 0.32 && gn > 0.35 && bn < 0.28) {
    return "YELLOW";
  }

  // ORANGE
  if (rn > 0.52 && gn > 0.18 && bn < 0.25) {
    return "ORANGE";
  }

  // PURPLE
  if (bn > 0.35 && rn > 0.28 && gn < 0.32) {
    return "PURPLE";
  }

  // PINK
  if (rn > 0.50 && bn > 0.22 && gn < 0.30) {
    return "P

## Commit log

2026-09-30 Copy project code and design documentation
    Current main-branch files copied from MSE2202/2026-project-pdf-team-004-5 (source commit dfe620768146762b33bcfbb2f8e2d5f7517985d2). Original team work by Aaggar68, jpan292, and liam-mcfadden. Origina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
    [MSE 2202B Lab-4 Team-5.xlsx]
2026-09-30 Copy CAD ramp model into original Model_Parts folder
    [Ramp.SLDPRT]
2026-09-30 Copy remaining original CAD models
    [2202_Chasis_Dimensioned.SLDPRT, HC-SR04-UltrasonicSensor v7.SLDPRT, Ramp_With_Catridge.SLDPRT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]
